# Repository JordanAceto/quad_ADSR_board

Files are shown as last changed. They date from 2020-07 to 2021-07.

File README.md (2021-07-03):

# Quad digital ADSR module

# *** Work in progress ***

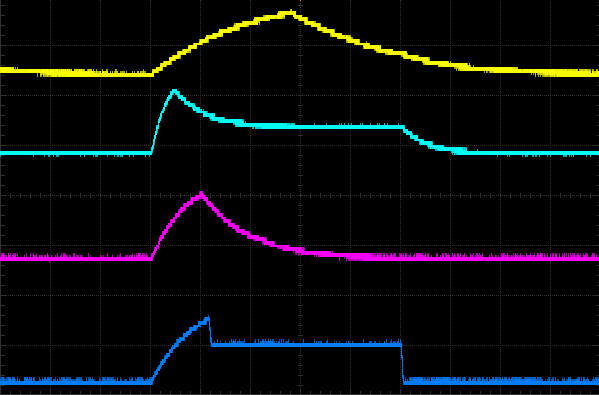
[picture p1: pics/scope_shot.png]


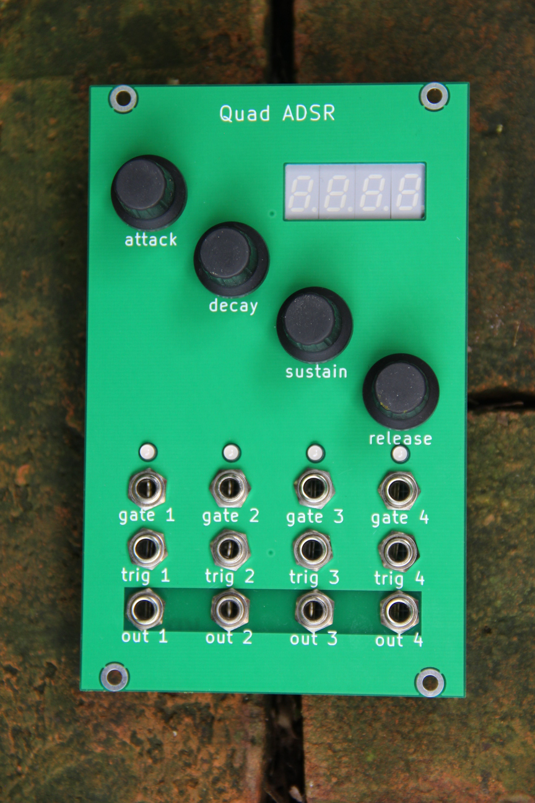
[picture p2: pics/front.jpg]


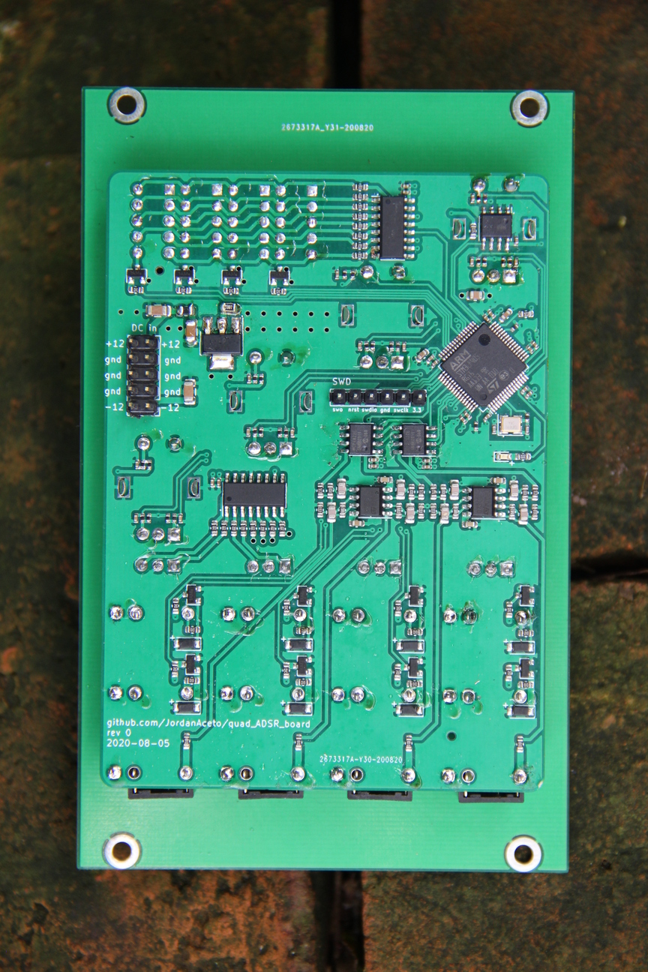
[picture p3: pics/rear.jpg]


## ADSRs are generated by an STM32 microcontroller and controlled by four encoders. A seven-segment display shows the most recently modified parameter.

One ADSR at a time is set as the "active" ADSR, which will be controlled by the encoders.

To select an ADSR as "active", the encoder push-button above a given ADSR is pressed.

The four-digit seven-segment display shows the parameter of the encoder that was most recently turned. For instance, if you just turned the decay time to 500 milliseconds, the display will show `0.500`. If you then adjust the sustain level to 68%, the display will now show `  68`. Time based parameters are shown in units of seconds, and sustain parameters are shown as 0% to 100%.

Additionally, the ADSRs can all be forced to lock to a "master" ADSR, so that that their attack, decay, sustain, and release parameters are all set the same. The four ADSRs can still be triggered independently in this mode, which makes this useful for polyphonic patches. This saves you from manually setting identical paramters four times. Lock-to-master mode is selected by performing a long push-switch press of the encoder above the desired ADSR. For instance, to force all the ADSRs to lock to the ADSR 3 settings, depress and hold the sustain encoder push-button for a few seconds. To leave lock-to-master mode, do a short click of any of the encoder push-buttons to select a new active ADSR.

A bank of four bi-color LEDs shows the active ADSR, and whether it is in independent, or lock-to-master mode.

# First rev build evaluation:
- Most of the systems work.
- __Done__ (but there is an I2C bug lurking, see the issues)~~The EEPROM has not been physically installed and EEPROM code has not been written yet.~~
- __DONE__ ~~In the code, when switching from lock-to-master mode back to independent mode: the ADSRs should go back to the settings they held before entering lock-to-master mode. Write a function called `release_ADSRs_from_master_mode` or something that accomplishes this, and call that function when leaving lock-to-master mode~~.
- __Done__ ~~The encoders should be no-detent types. I used encoders with detents and I don't like it.~~
- I tried and failed to setup encoder trigger filtering, please investigate using the timer register filters when the timers are in encoder mode. I'd like to be able to apply filtering to the encoders. They work fine and don't misfire now, but it would be nice to easily tailor how "fast" they update by addign in some filtering.
- __This really isn't that bad__ ~~The heights of the panel mount components is an issue: the 3.5mm jacks are taller than the encoders and the seven-segment display. I got everything to work by lifting the encoders and 7-seg up off the pcb before soldering, but this is lame. I think the solution is split the pcb into a main pcb and a jack pcb, and connect the two pcbs with wires. Another solution could be to create a "lifter" pcb that acts as a spacer between the main pcb and the encoders/7-seg, but this seems kind of yucky too. Think about this for a while before doing a new pcb rev.~~
- I'm having issues with getting the PLL to work for arbitrary frequencies: with some settings of M, N, and P the output frequency is not as expected. Please investigate this and figure out what I'm doing wrong.
- I used two MCP4822 DACs, but I probably could have used the 2 internal DAC channels for 2 of the ADSRs and only installed one MCP4822. Investigate if using the internal DAC for 2 channels creates any pinout conflicts, or any other kind of conflicts, for the next board revision, to try and save a DAC.
- The ADSR outputs are low: I want 10v peak ADSRs and I calculated the opamp gain resistors assuming the DACs output 3.3v peaks, but they don't. Please recalculate the gain resistors for the actual MCP4822 output with a gain of 1x. Take into account the internal DACs if you apply the suggestion above.
- __DONE__ (enabled FPU and changed signals to floats) ~~Many parts of the codebase could be optimized and improved. In particular, the ADSR code does some costly 64-bit divisions in a couple of spots. See if you can't improve this. View the `main.list` output file occasionally~~.
- __DONE__ (works ok but be on the lookout) ~~Compiler optimization is turned off right now. Turn this up to `-Os` or `-O2` and make sure that nothing breaks. There might be some volatile issues, or necessary code that gets optimized away, be careful and thorough!~~
- Otherwise the project is in pretty good shape! The prototype I built could definitely go in a rack and work with other modules.

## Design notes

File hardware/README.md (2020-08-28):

# This subdirectory contains documents for buiding the hardware for the system.

- ### All schematic capture and pcb layout is done using kicad.

- ### `main_pcb` contains everything you need to build and/or modify the main circuit board. 

- ### `front_panel` contains documents for making a low cost pcb front panel.

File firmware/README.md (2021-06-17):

# stm32f405 firmware for Quad ADSR eurorack module

## Brief description:

Four ADSR envelope generators are created in software via Direct Digital Synthesis.

Four encoders allow the user to set the attack, decay, sustain, and release parameters.

By clicking on the encoder that is in line with the jacks associated with a given ADSR, that 
ADSR is selected as the "active ADSR", and the encoders will adjust the parameters for that 
envelope only.

Performing a long button press forces all four ADSRs to lock to the ADSR associated with 
the encoder that was pressed. Now all four ADSRs will have the same attack, decay, sustain, 
and release parameters, and the encoders will update all four ADSRs simultaneously. This is
called "lock-to-master" mode. The primary use of lock-to-master mode is for polyphonic patches, 
you can easily have four ADSRs that share the same settings but can be triggered independently.

By doing a quick press of any encoder button the system will exit lock-to-master and the ADSRs will 
go back to independent mode, and their old settings will be restored.

The four digit seven-segment display shows the setting of the paramter that was most recently adjusted. 
Attack, decay, and release times are shown in seconds and milliseconds, and the sustain parameter is shown
as a percent from 0.0 to 100.

The settings for the ADSRs are remembered in EEPROM memory. The system automatically stores the settings in
the EEPROM every few minutes if they have changed.

---

## This is a CMSIS/Makefile type project.
- The bare minimum stm supplied CMSIS and startup files are included in appropriate directories.
- The rest of the code is hand written `C` which uses the CMSIS headers to manipulate registers and peripherals.
- A Makefile is included to build/clean/flash the project.
- An st-link device is used to flash the f405.

---
## Prerequisites:
- [arm-none-eabi toolchain](https://developer.arm.com/tools-and-software/open-source-software/developer-tools/gnu-toolchain/gnu-rm/downloads)
- [GNU make](https://www.gnu.org/software/make/)
- [st-link utility](https://www.st.com/en/development-tools/stsw-link004.html)
- A physical st-link device. I use an old Nucleo board.
- If you have a different preferred method of flashing STM32 chips then feel free to go wild.

---

### To build the project:
- `$ make`

### To flash an STM32f405 chip connected to an st-link programmer via the SWD header:
- `$ make write`

---

### The attack and decay curves are stored in lookup tables which are generated via a python script.

You can tweak the curves via the command line (requires python/numpy/matplotlib).

To view a plot of the attack and decay curves:
- `$ make plot_lut`

To tweak the curves and then view the results:
- `make plot_lut ATTACK_TARGET=<number between 1 and 5> NUM_TIME_CONSTANTS=<number between 3 and 10>`

To overwrite the C header and source files with tweaked curves:
- `$ make write_lut ATTACK_TARGET=<number between 1 and 5> NUM_TIME_CONSTANTS=<number between 3 and 10>`

To overwrite the C header and source files with default curves:
- `$ make write_lut`

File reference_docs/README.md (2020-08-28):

# The `reference_docs` directory contains various technical documents related to the parts used by the system

- ### `stm32_docs` contains the data sheet, reference manual, and errata for the stm32f405 microcontroller used by the system, as well as the cortex-M4 programmers manual.

- ### `misc_datasheets` contains datasheets for the other electronic parts used by the system: the DAC, opamps, shift registers, LEDs, etc.

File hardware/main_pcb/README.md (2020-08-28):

# Main pcb

## This subdirectory contains the documents needed to build and/or modify the main pcb.

---
### The general outline of the hardware:
- An stm32f405 generates four ADSRs digitally using DDS/look up tables.
- Four encoders control the Attack, Decay, Sustain, and Release parameters.
- The ADSR signals are sent to two MCP4822 SPI DACs.
- The MCP4822 DACs feed four opamp lowpass filters which smooth, scale, and buffer the output signals.
- A seven segment LED display and four bicolor LEDs are driven by shift registers connected to the SPI bus.
- An EEPROM is driven by the I2C bus.
- NPN transistors buffer the microcontroller inputs from the outside world.
- A standard Eurorack style power input header is used for the +/- 12vdc power input.
- The opamps are powered directly by the +/- 12vdc input.
- A 3.3v regulator provides power to the low voltage parts of the system.

---
### `kicad_docs` contains all the files needed to open the project in kicad.
- If you want to modify the project, go in here.
---
### `construction_docs` contains the files needed to build the project:
- A pdf copy of the schematic.
- An interactive BOM that can be opened in a web browser.
- Complete gerbers for the pcb, and a zipped copy of all the gerbers.
- Files for using the cheap smt assembly service from jlcpcb. Most of the small parts are included. The DACs and EEPROM were left out because they were extended parts at jlc at the time I ordered.
- If you use the jlcpcb assembly service, you'll still need to hand install the DACs, EEPROM, and all the through hole parts.

---
### `pics` contains a few rendered pics of the pcb

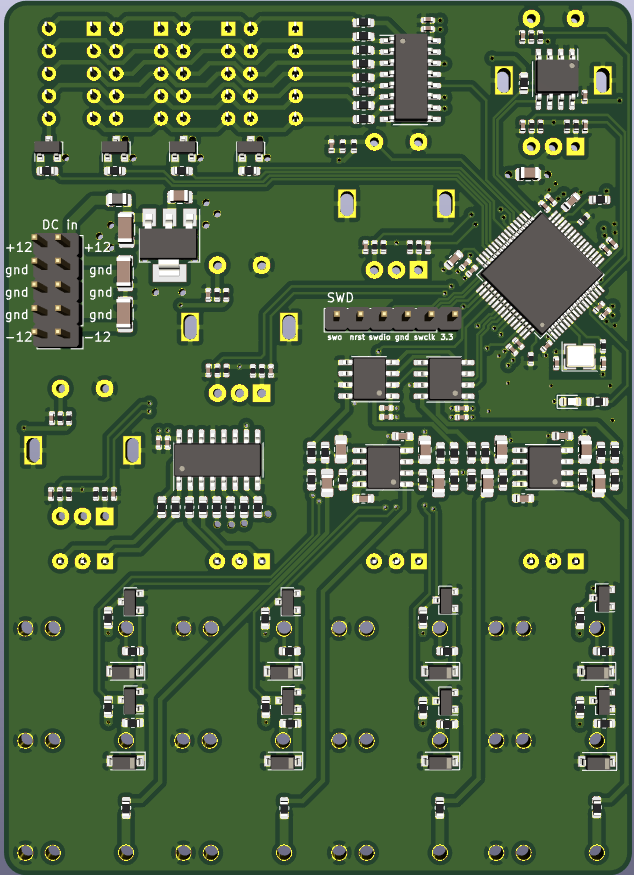
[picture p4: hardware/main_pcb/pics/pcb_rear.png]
pcb rear


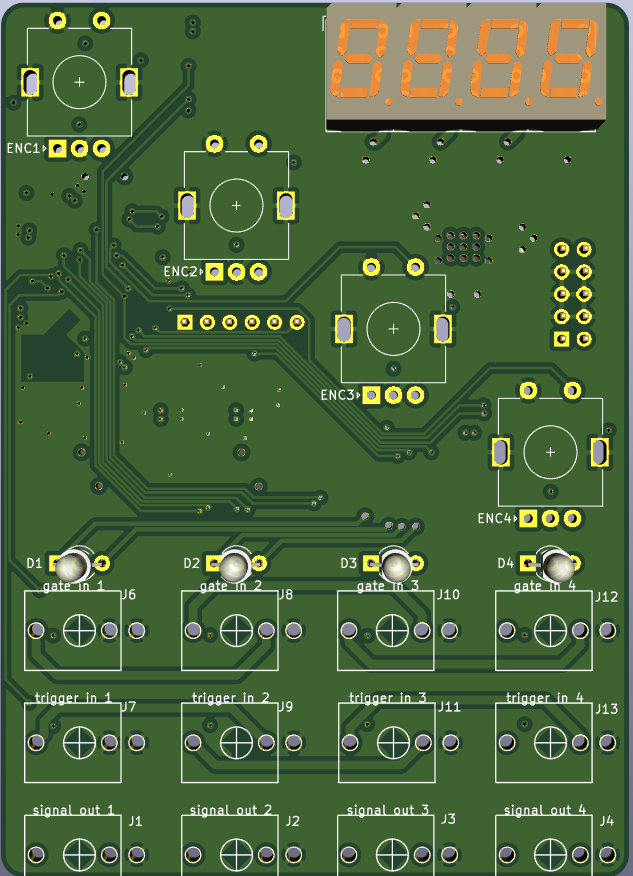
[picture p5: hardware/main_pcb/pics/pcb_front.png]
pcb front


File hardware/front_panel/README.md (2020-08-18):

# Quad ADSR front panel

Low cost pcb front panel option

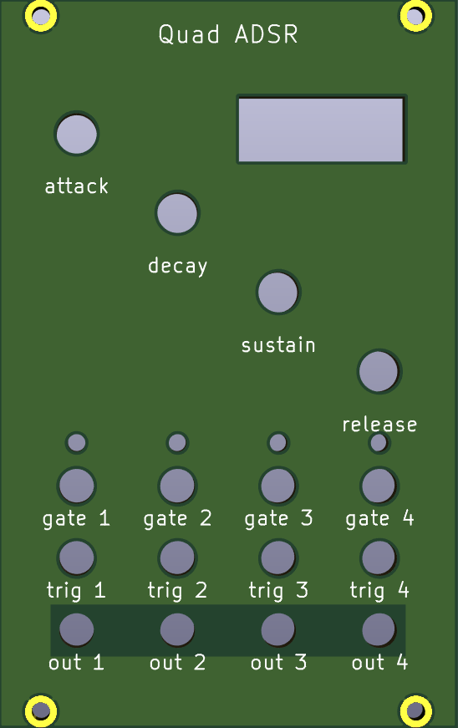
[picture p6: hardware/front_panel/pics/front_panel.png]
front panel


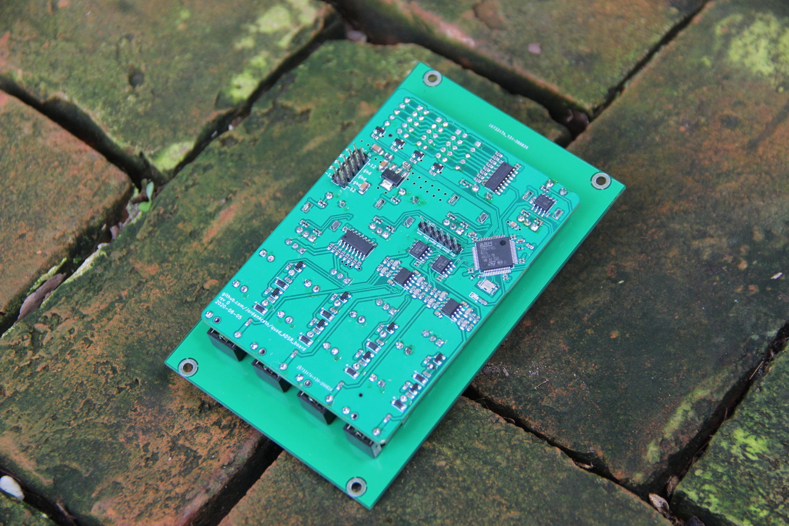
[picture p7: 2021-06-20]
pics/rear_angle.jpg

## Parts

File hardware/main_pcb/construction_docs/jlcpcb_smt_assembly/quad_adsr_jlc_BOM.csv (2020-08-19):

Designator | Quantity | Value | Footprint | LCSC Part #
C1, C2, C4, C5, C7, C8, C10, C11, | 8 | 10nF | 0402 | C15195
C3, C6, C9, C12, C16, C17, C18, C19, C20, C21, C22, C23, C24, C25, C26, C27, C28, C29, C30, C31, C32, C49, C50, C53, | 24 | 100nF | 0402 | C1525
C13, C51, C52, | 3 | 10uF | 1206 | C13585
C14, C15, | 2 | 10uF | 0805 | C15850
C33, C34, C35, C36, | 4 | 100nF | 0603 | C14663
C37, C38, C39, C40, C41, C42, C43, C44, | 8 | 2n2 | 0805 | C28260
C45, C46, | 2 | 2.2uF | 0603 | C23630
C47, C48, | 2 | 12pF | 0402 | C1547
D5, | 1 | LED | 0603 | C72043
D6, D7, D8, D9, D10, D11, D12, D13, | 8 | 1N4148W | SOD-123 | C81598
FB1, | 1 | Ferrite_Bead_Small | 0805 | C1015
HSE1, | 1 | 16MHz | SMD-3225_4P | C13738
Q1, Q2, Q3, Q4, Q5, Q6, Q7, Q8, Q9, Q10, Q11, Q12, | 12 | MMBT3904 | SOT-23 | C20526
R1, R2, R3, R4, R7, R8, R9, R10, R13, R14, R15, R16, R19, R20, R21, R22, R82, R83, | 18 | 10k | 0402 | C25744
R5, R11, R17, R23, | 4 | 4k7 | 0402 | C25900
R6, R12, R18, R24, R84, | 5 | 100 | 0402 | C25076
R25, R34, R35, R36, R50, R52, R54, R56, R58, R60, R62, R64, | 12 | 10k | 0603 | C25804
R26, R27, R28, R29, R30, R31, R32, R33, R37, R38, R39, R40, R41, R42, R43, R44, | 16 | 390 | 0603 | C23151
R45, R46, R47, R48, | 4 | 1k | 0603 | C21190
R49, R51, R53, R55, R57, R59, R61, R63, | 8 | 100k | 0603 | C25803
R65, R66, R73, R74, | 4 | 50k | 0603 | C23196
R67, R68, R75, R76, | 4 | 200k | 0603 | C25811
R69, R70, R77, R78, | 4 | 33k | 0603 | C4216
R71, R72, R79, R80, | 4 | 68k | 6030 | C23231
R81, | 1 | 2k2 | 0603 | C4190
R85, R86, | 2 | 4k7 | 0603 | C23162
U2, U6, | 2 | 74HC595 | SOIC-16_3.9x9.9_1.27P | C5947
U7, | 1 | AMS1117-3.3 | SOT-223 | C6186
U8, U11, | 2 | TL072 | SOIC-8_3.9x4.9_1.27P | C6961
U12, | 1 | STM32F405RGTx | LQFP-64_10x10_P0.5P | C15742

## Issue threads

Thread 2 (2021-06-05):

Trouble hitting arbitrary frequencies with PLL

JordanAceto, 2021-06-05:
In the RCC clock configuration code, I am not able to set the PLL multipliers/dividers such that the output frequency is as expected for all frequencies.

Right now I have it hitting 50MHz with M, N, and P settings that make sense.

But, if I try to set the clock to 84MHz using M, N, and P settings that seem like they should work, the actual output frequency is not correct.

See the code in RCC.c for details. There is commented out code to output the divided PLL on one of the GPIO pins for monitoring. You can also toggle the LED or something in one of the timer ISRs to see if the frequencies make sense.

I suspect this may have something to do with the order of the clock initialization, or perhaps I'm not setting up the FLASH wait states correctly for fast clocks.

50MHz is probably fine for the final clock frequency, but I'd like to know what I'm doing wrong and be able to set the clock to arbitrary (legal) frequencies.

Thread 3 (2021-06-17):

I2C2 goes into infinite loop without small delay

JordanAceto, 2021-06-17:
After writing to the EEPROM via I2C2, if you attempt to read or write again immediately the system will go into an infinite loop.

A hack that seems to stop this is putting a few millisecond delay at the end of the I2C2_memory_write function.

However, this is not ideal, as the delay could happen at an annoying time if the user is playing, causing a discontinuity.

Something about the way I'm writing/reading/initializing I2C2 is wrong, but I'm not sure what it is yet. Please investigate and fix the I2C2 code, and then remove the delay at the end of the I2C2_memory_write function.

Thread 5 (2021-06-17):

ADSR outputs are low

JordanAceto, 2021-06-17:
The outputs of the ADSRs are supposed to range [0v, +10v], but they don't.

I calculated the gain of the opamp lowpass filters/level shifters assuming the DACs went up to +3.3v, but they don't, more like +2v and change.

The exact amplitude of the ADSRs isn't critical, but it would be nice if they went to a level that seemed on purpose :P

Please recalculate the gain-setting resistors of the opamps so that the ADSR final outputs go to +10 volts.

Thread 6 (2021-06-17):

TIM6 and TIM7 init could be cleaned up

JordanAceto, 2021-06-17:
The initialization code for timers TIM6 and TIM7 uses magic numbers, and I'm not even sure what frequency I was trying to hit with  TIM7.

It should be possible to use the value of the system clock frequency to calculate the PSC and ARR register values to hit a desired  timer frequency.

TIM6 must match the sample rate for the ADSRs. It's important that this one is fast and not-too-jittery.

TIM7 is not critical, it updates the UI and can be pretty slow as long as the LEDs don't flicker. I think I was going for 1kHz.

Please remove the magic numbers and use the symbol for the system clock frequency to calculate the desired register values, and include some comments about what the times mean.

JordanAceto, 2021-07-04:
Done

Closed 2021-07-04.

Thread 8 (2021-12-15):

DAC2 CS pin is on a bad pin

JordanAceto, 2021-12-15:
The chip select pin for DAC2 is PB4 on the stm32. This is also the NJTRST JTAG pin. There is a workaround in the GPIO.c file that deals with the MODER bits, but it would be better if it were on a different pin, there are plenty available. See the comment in GPIO.c set_SPI_CS_pins_to_output() function implementation for more details.

When a board revision happens, consider moving this pin. Changes will need to be made to the PCB layout, GPIO.c, and GPIO.h

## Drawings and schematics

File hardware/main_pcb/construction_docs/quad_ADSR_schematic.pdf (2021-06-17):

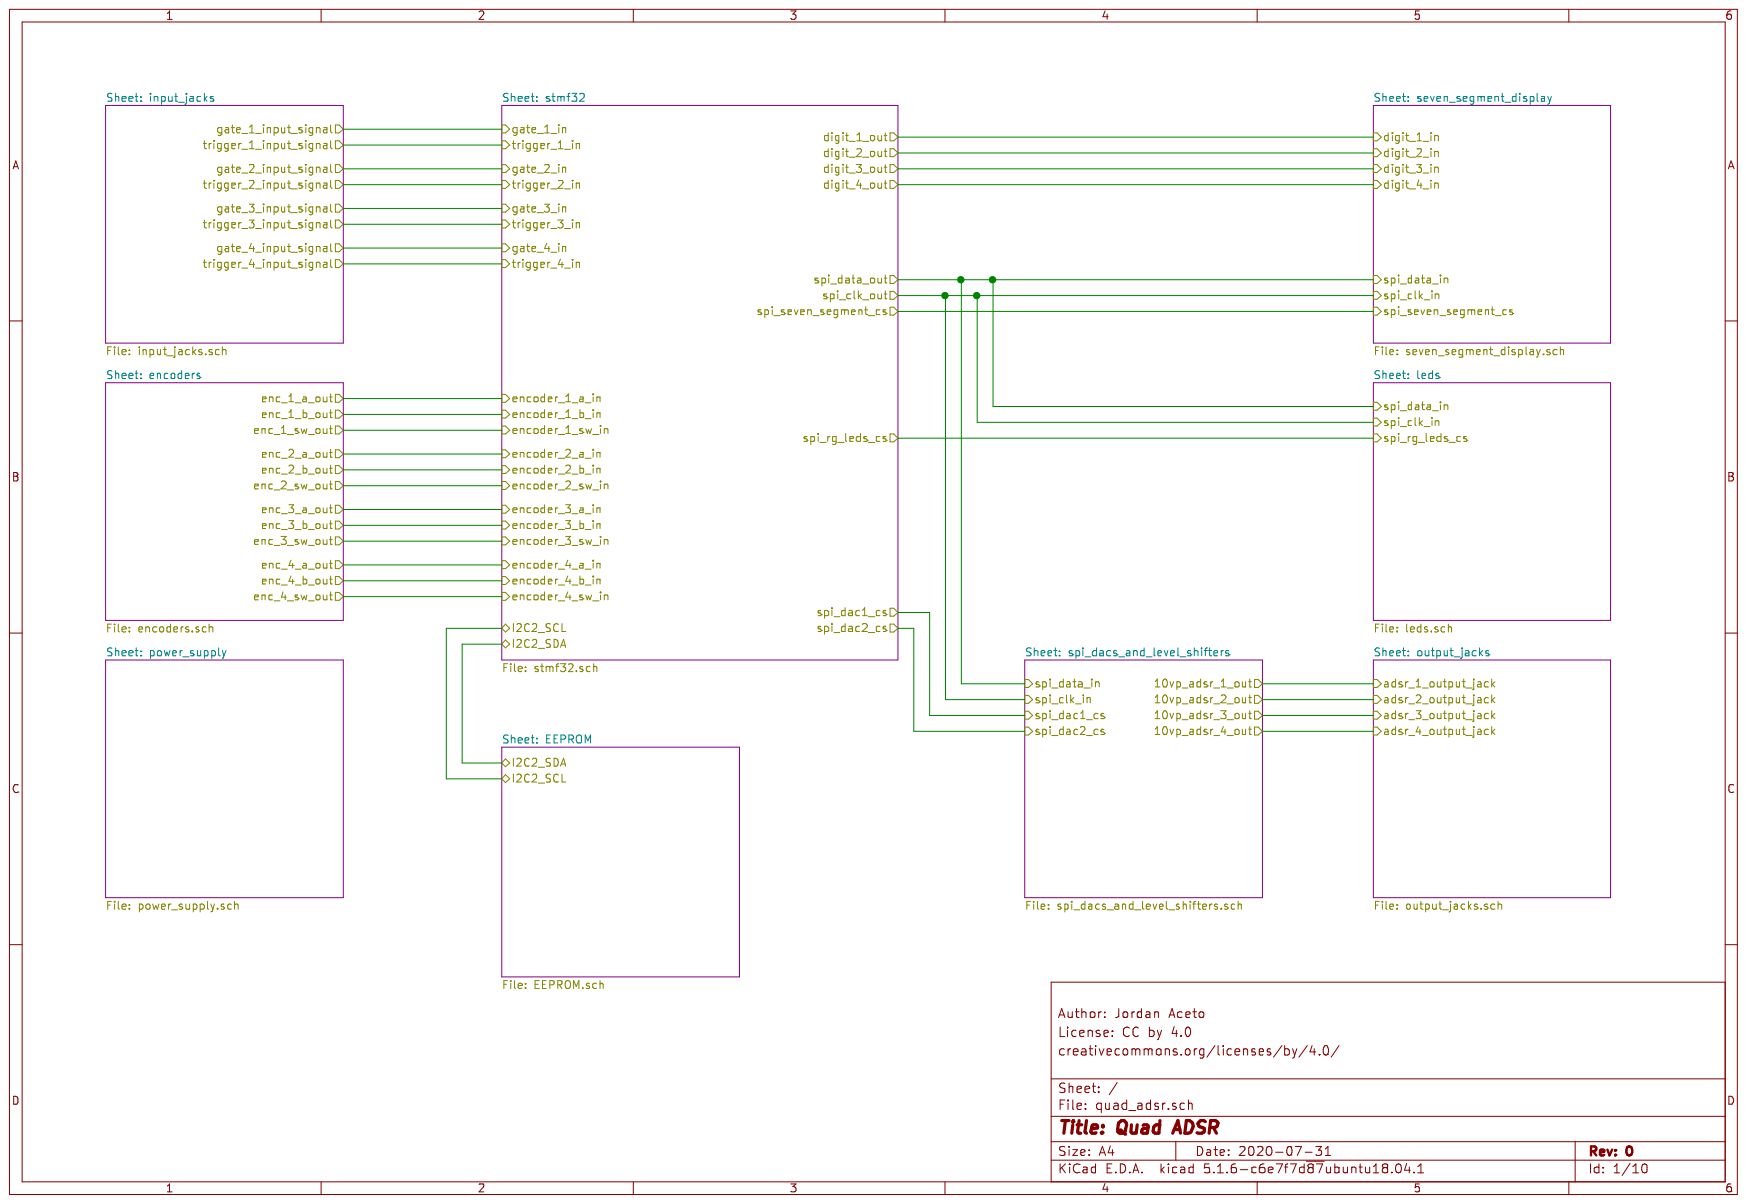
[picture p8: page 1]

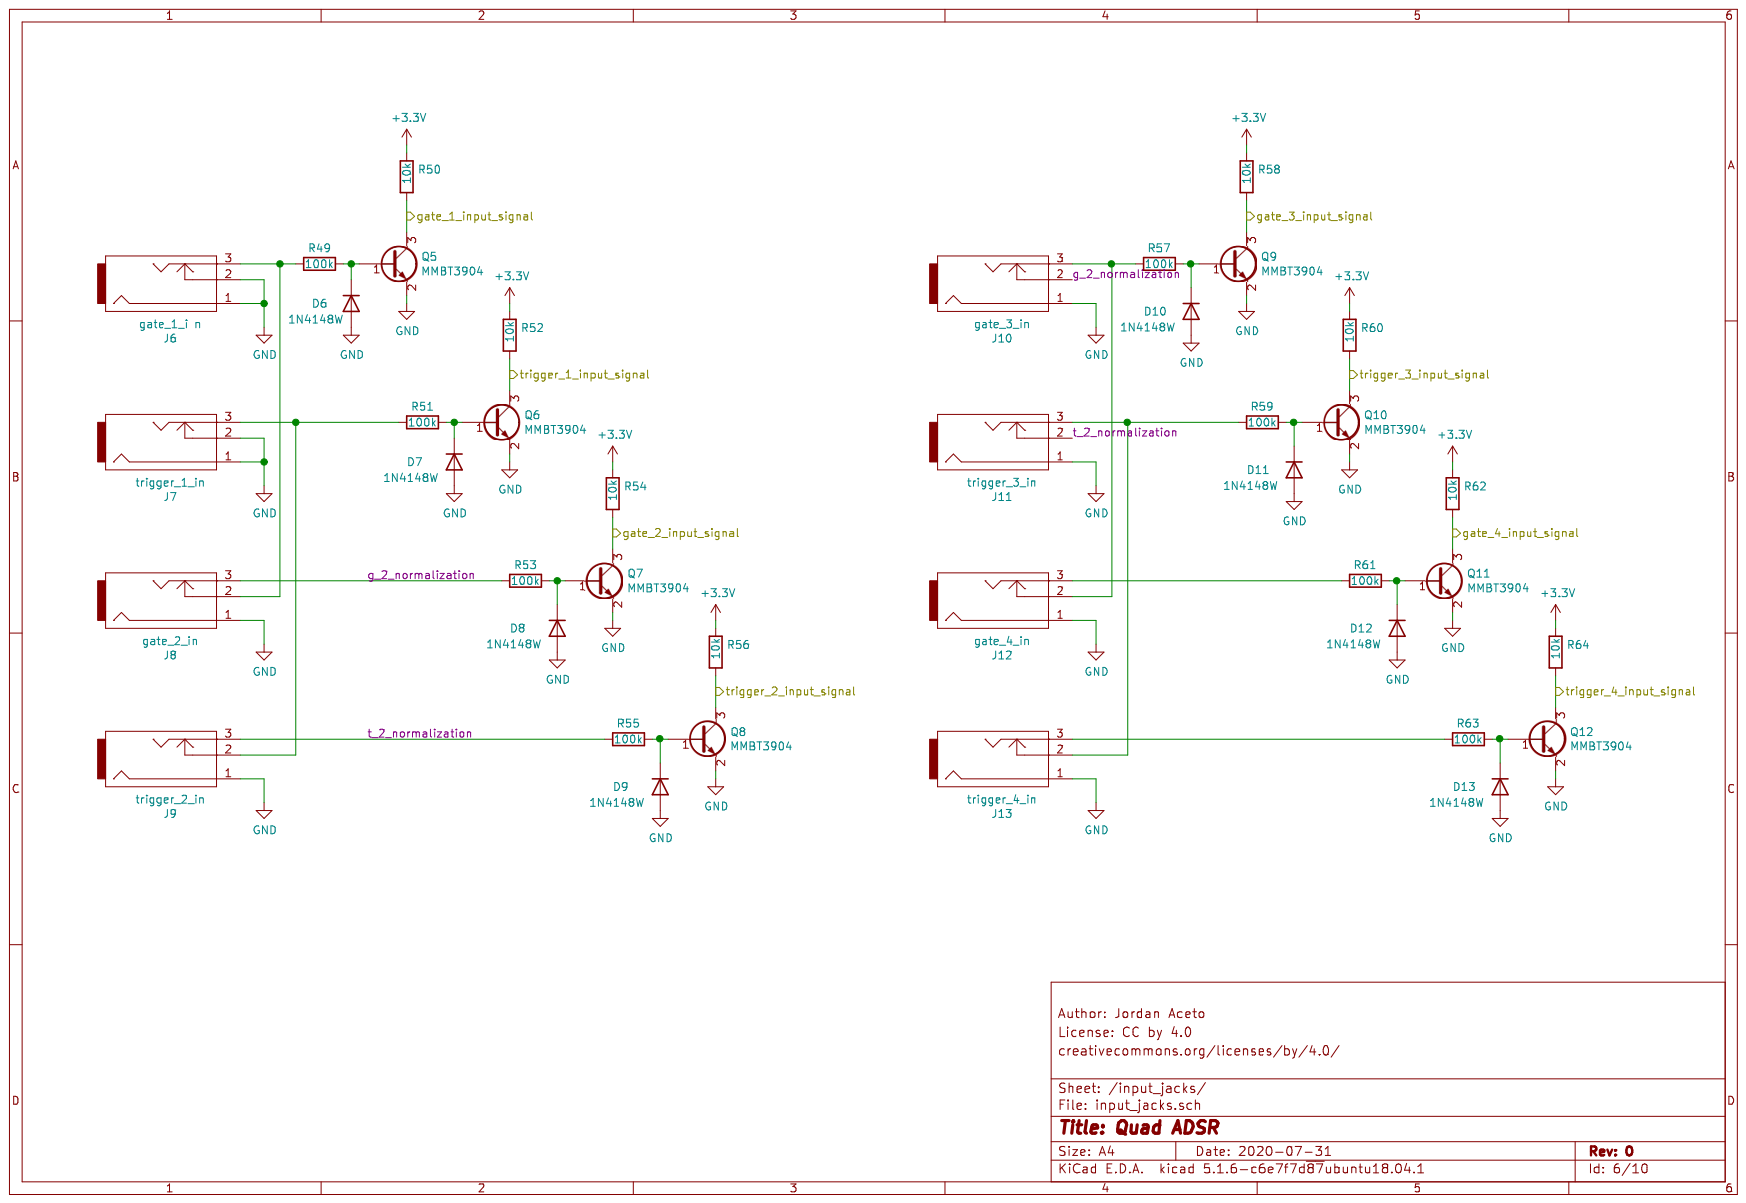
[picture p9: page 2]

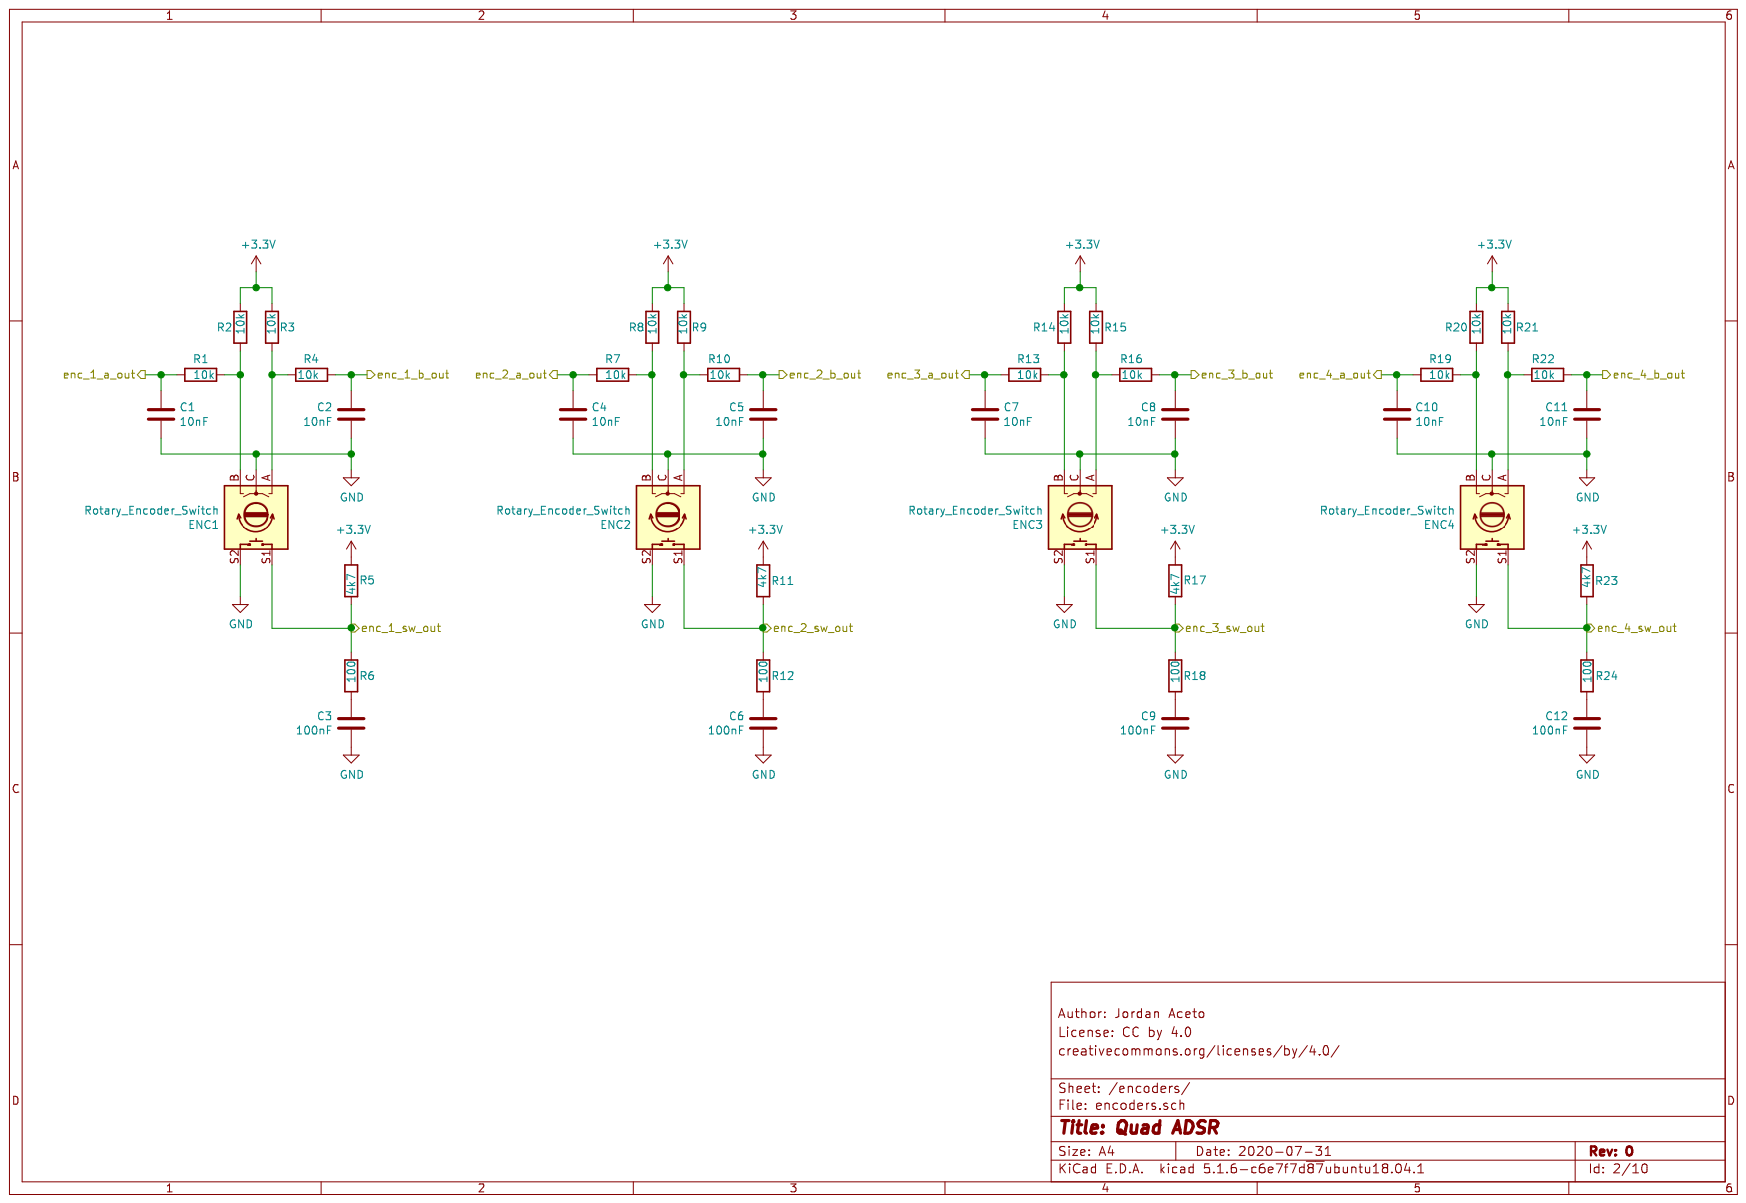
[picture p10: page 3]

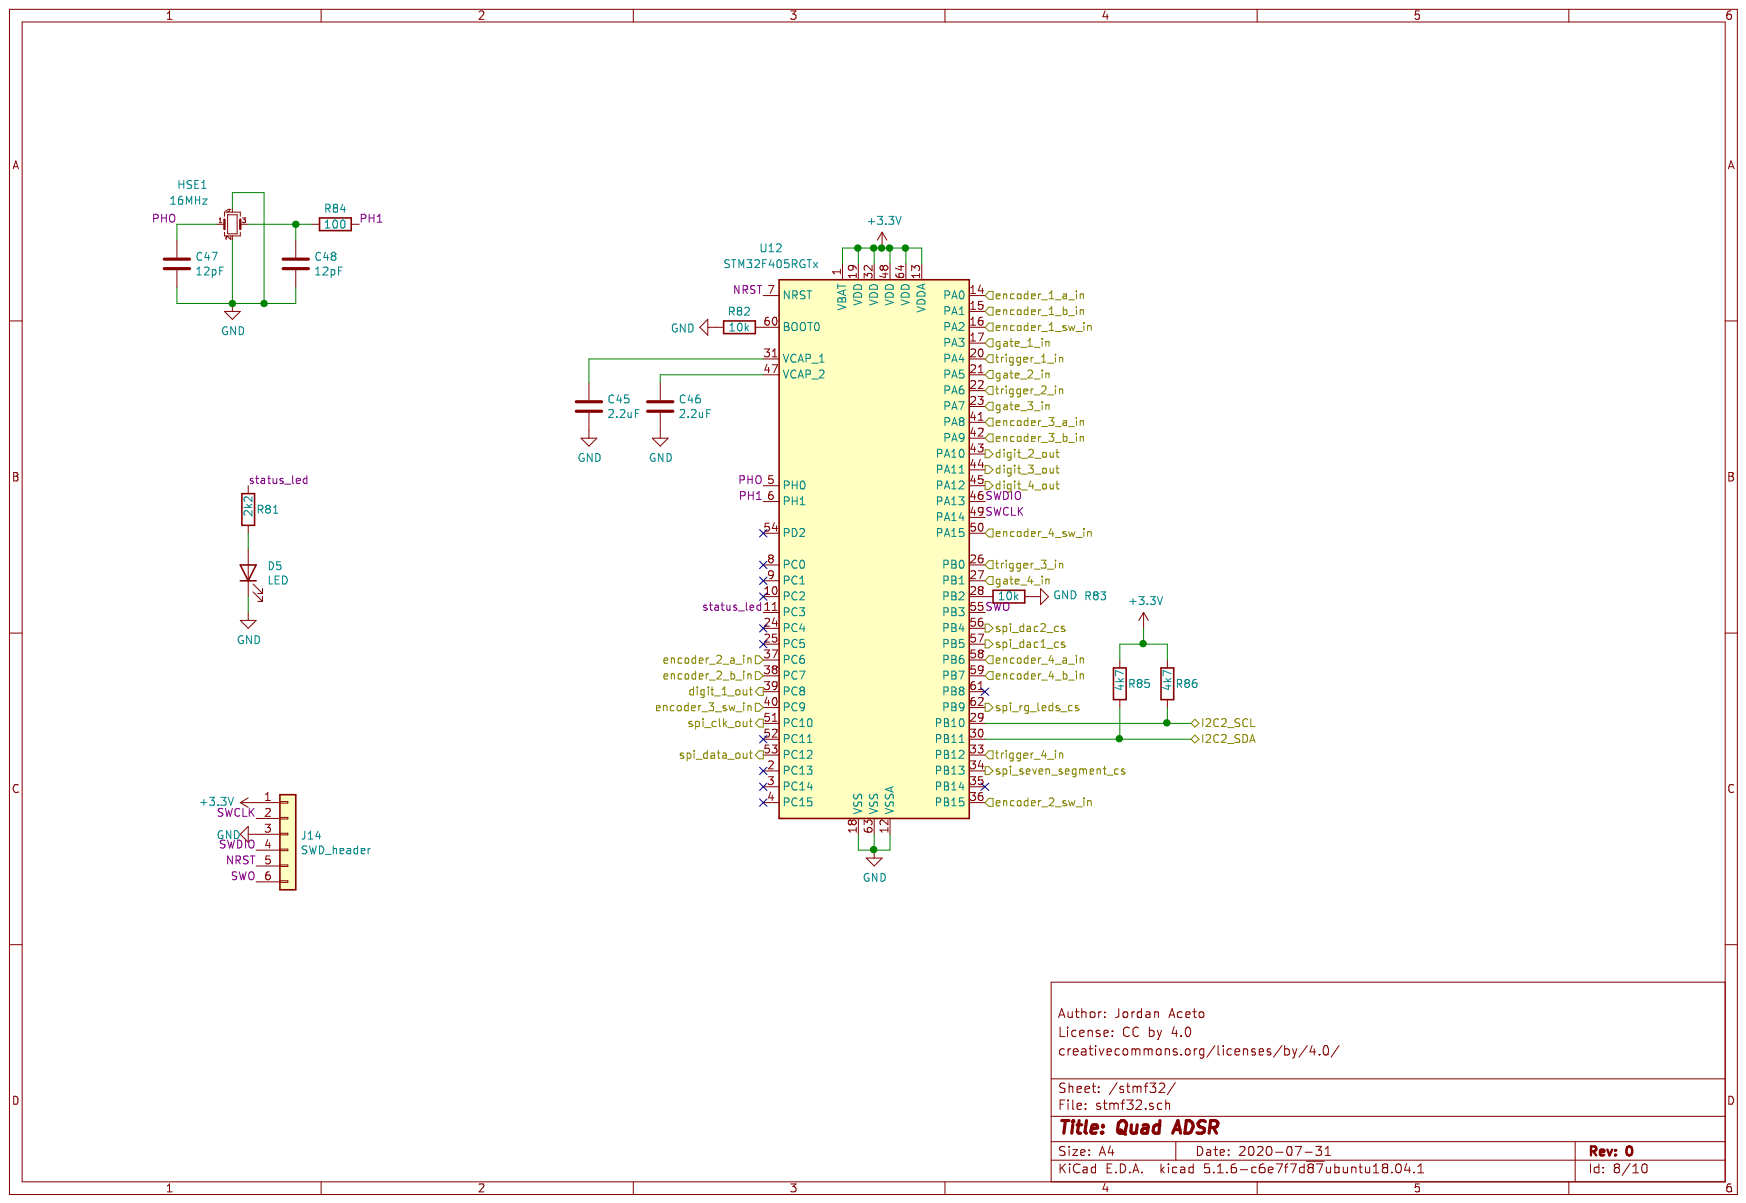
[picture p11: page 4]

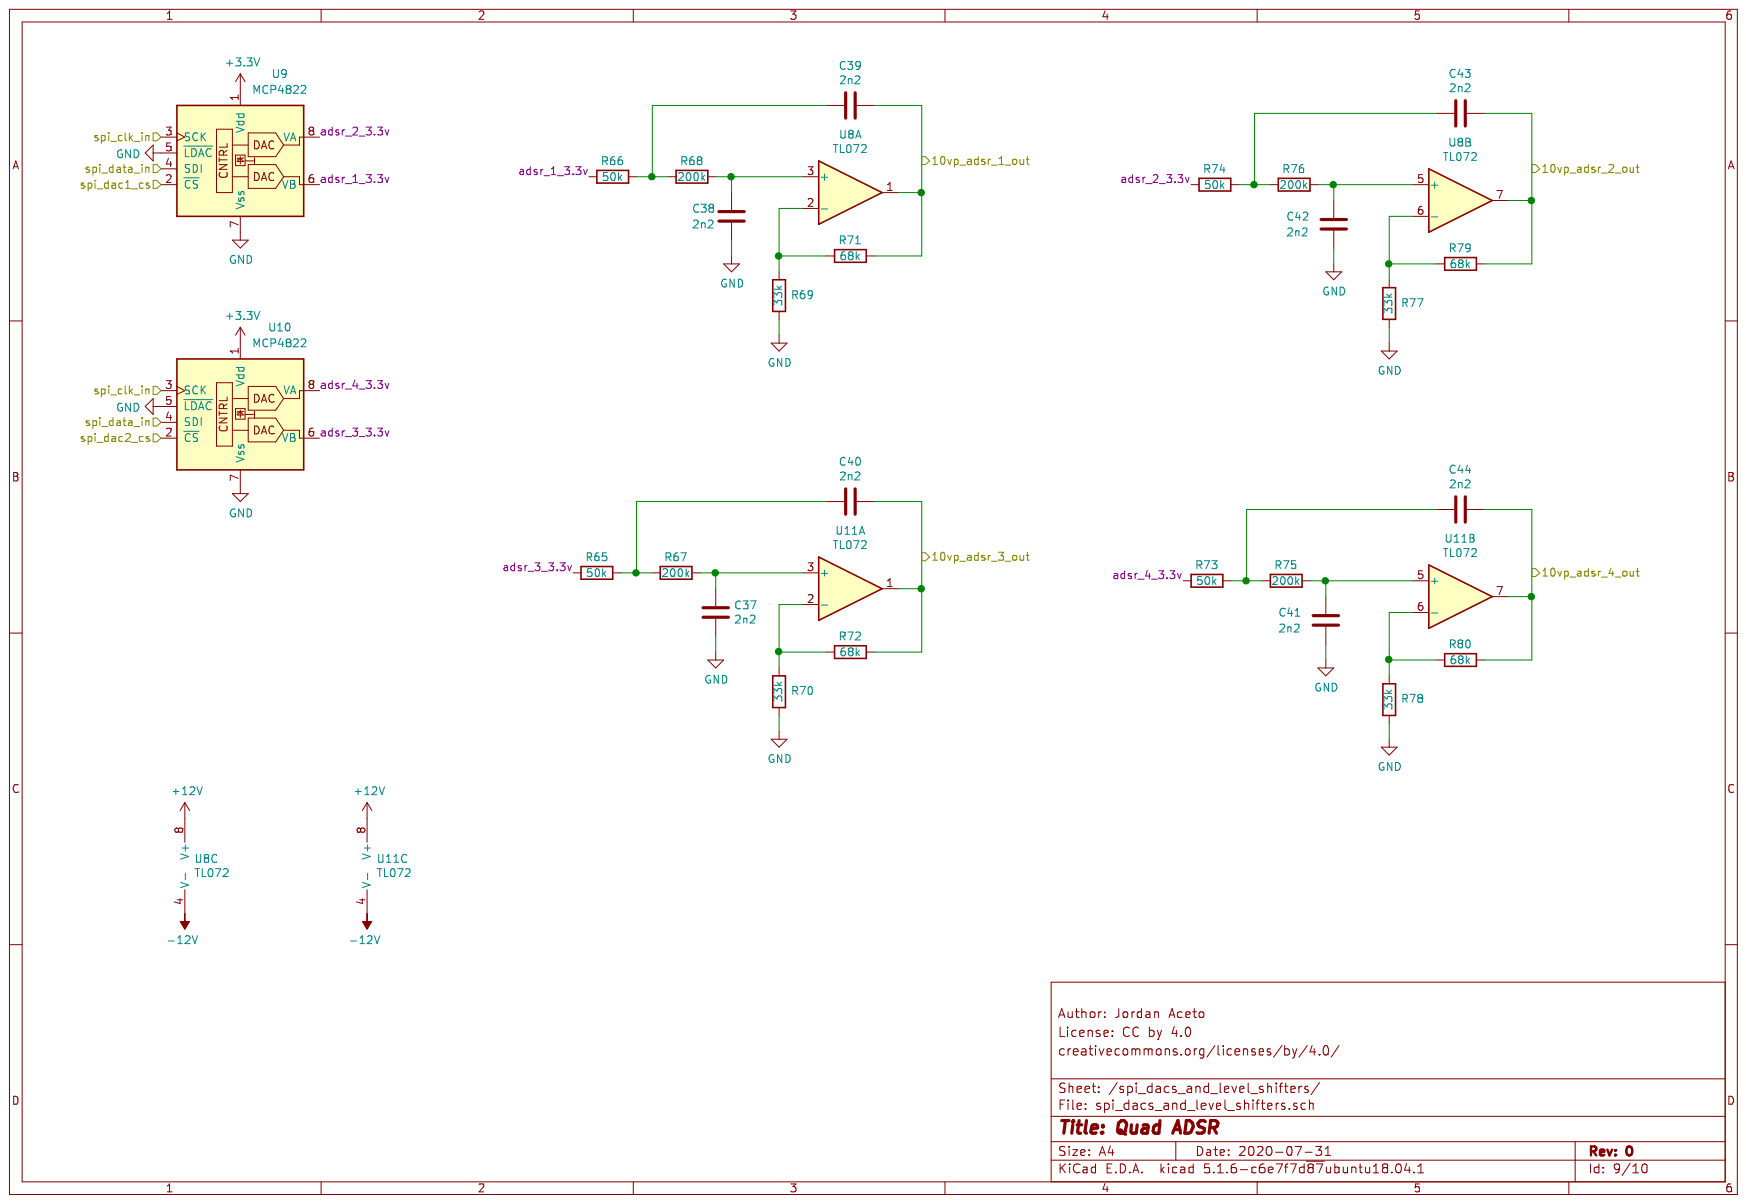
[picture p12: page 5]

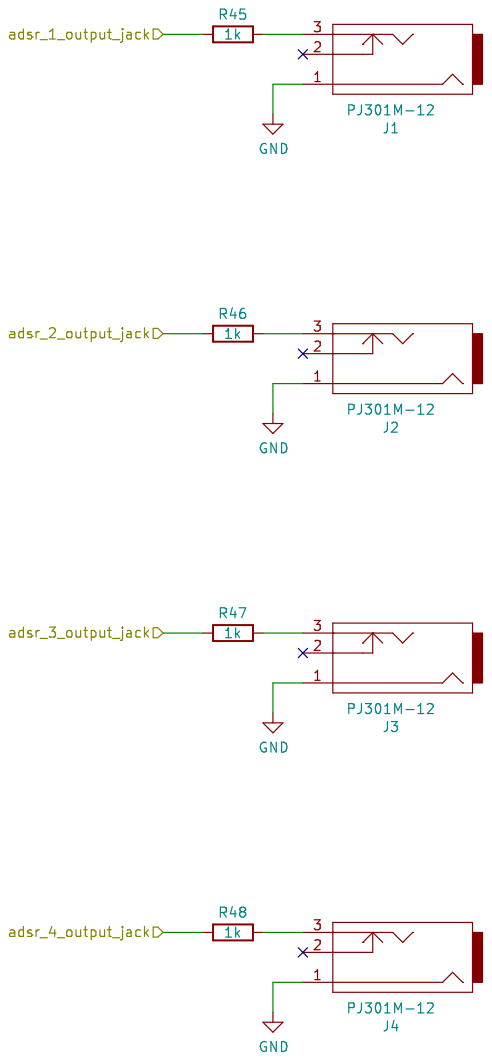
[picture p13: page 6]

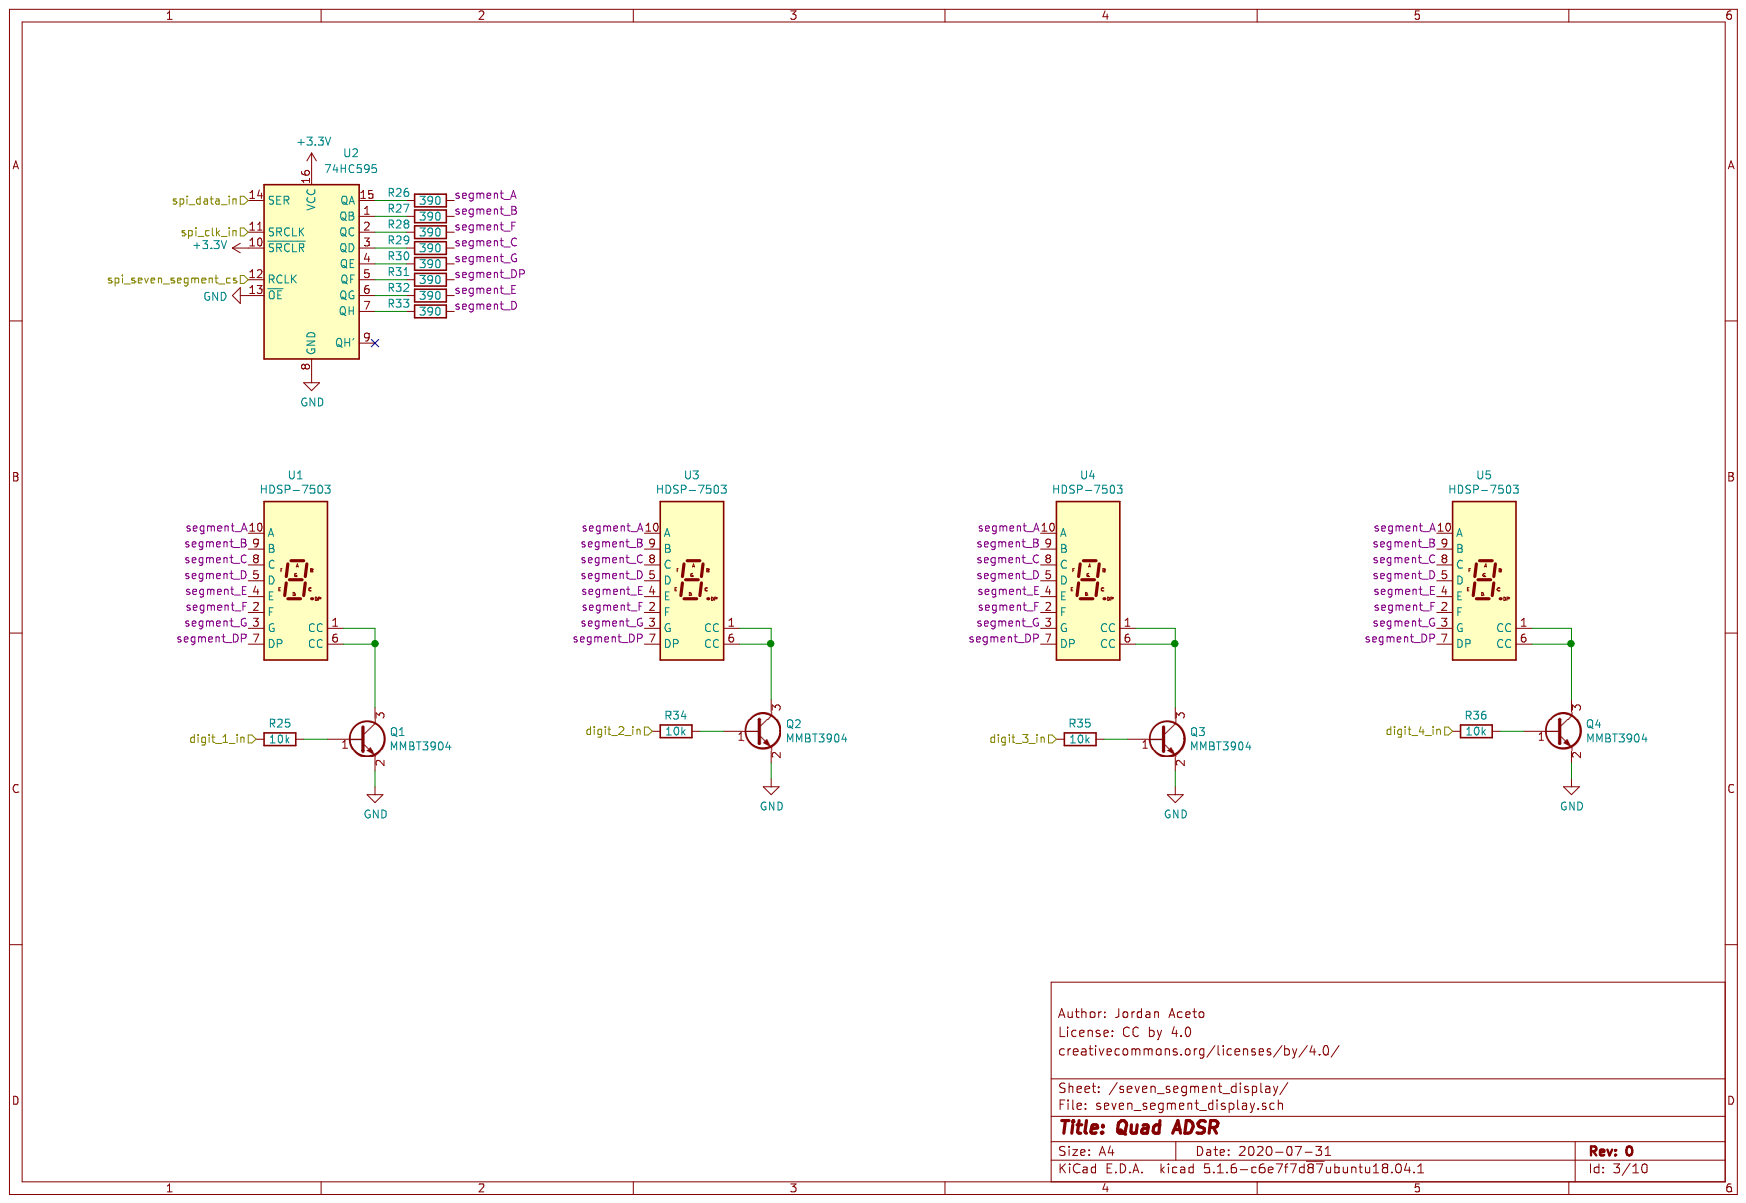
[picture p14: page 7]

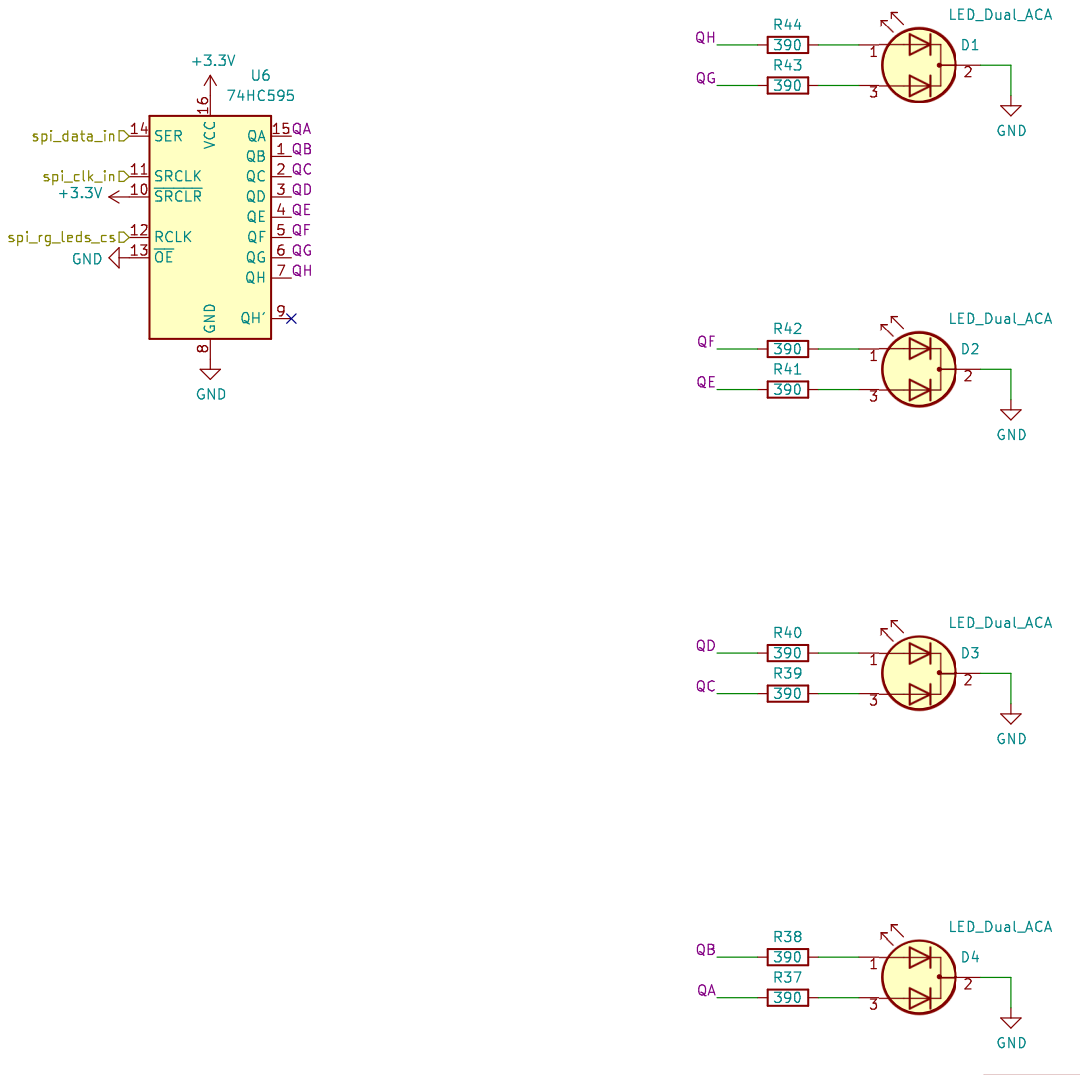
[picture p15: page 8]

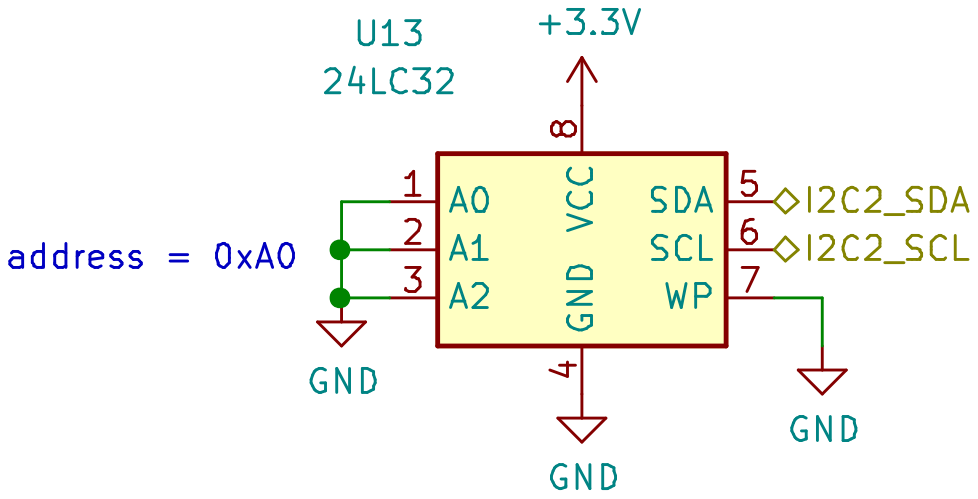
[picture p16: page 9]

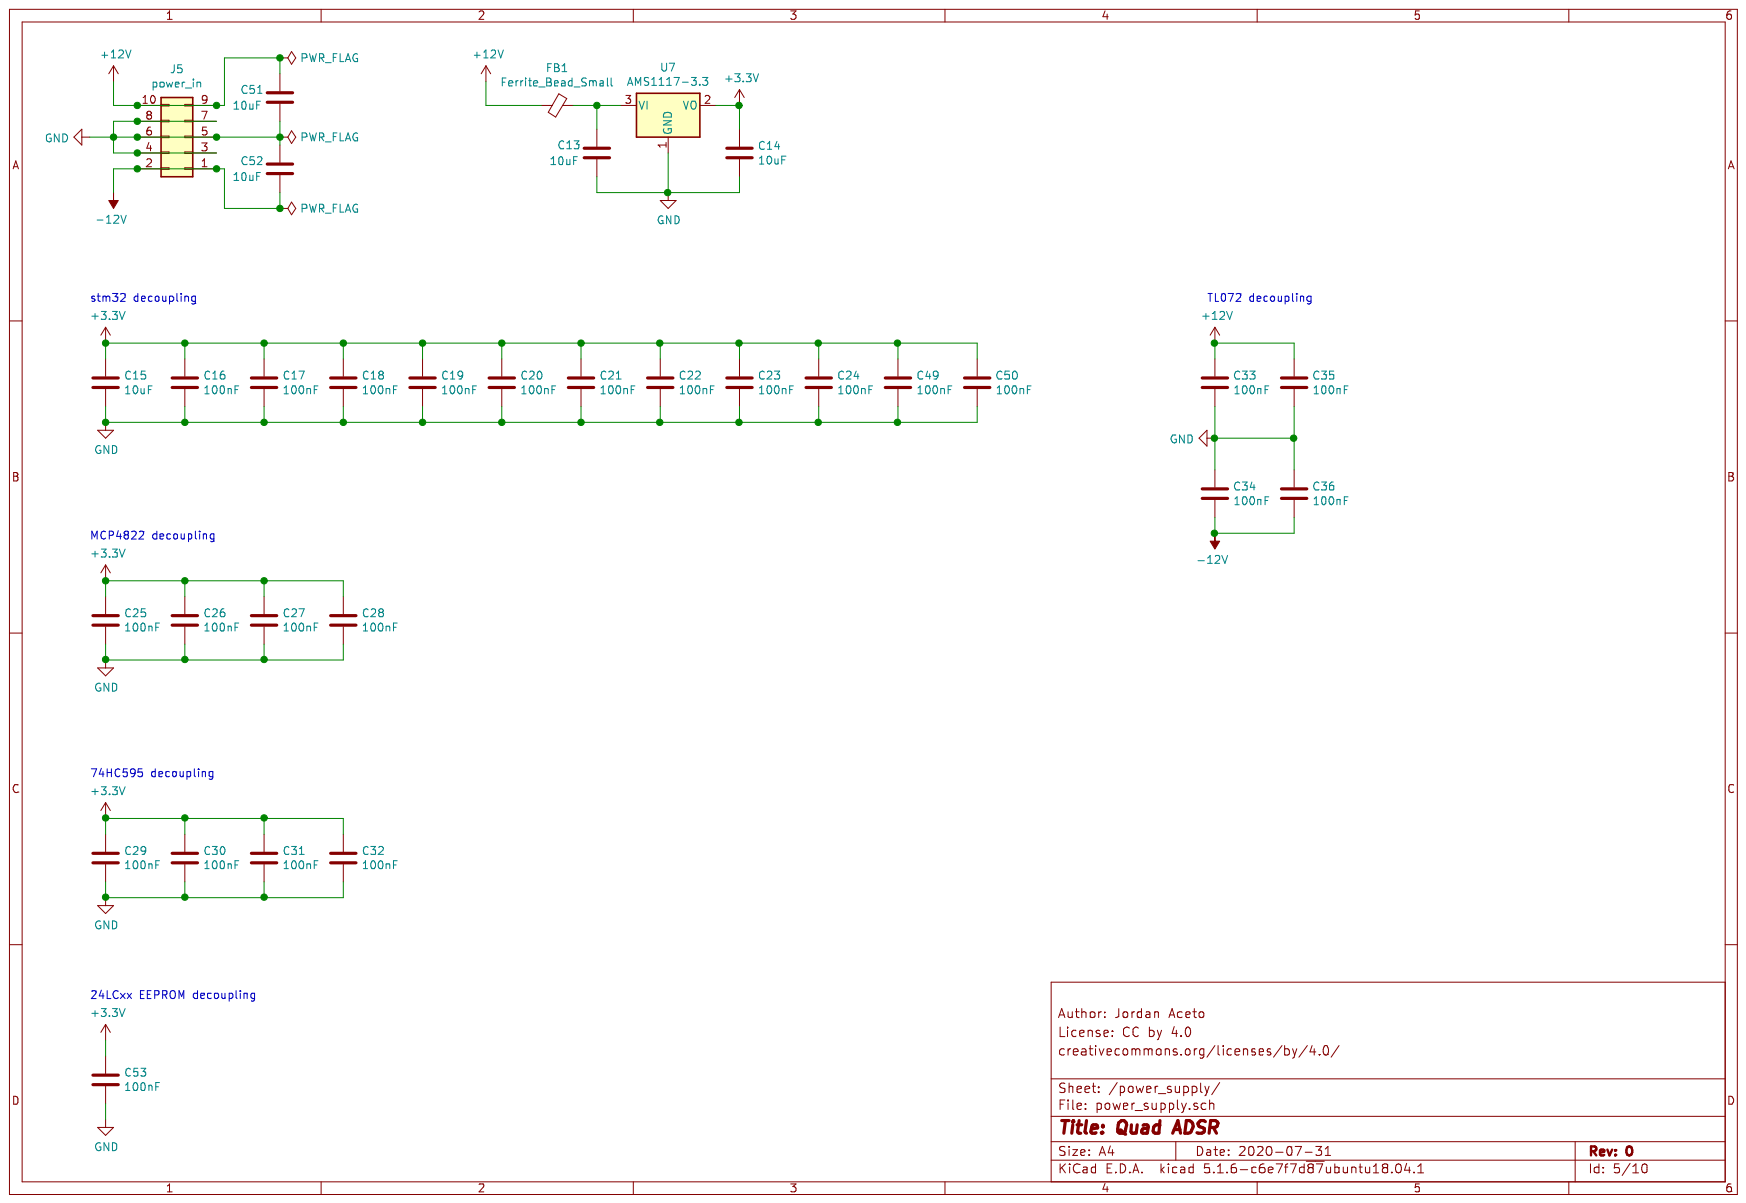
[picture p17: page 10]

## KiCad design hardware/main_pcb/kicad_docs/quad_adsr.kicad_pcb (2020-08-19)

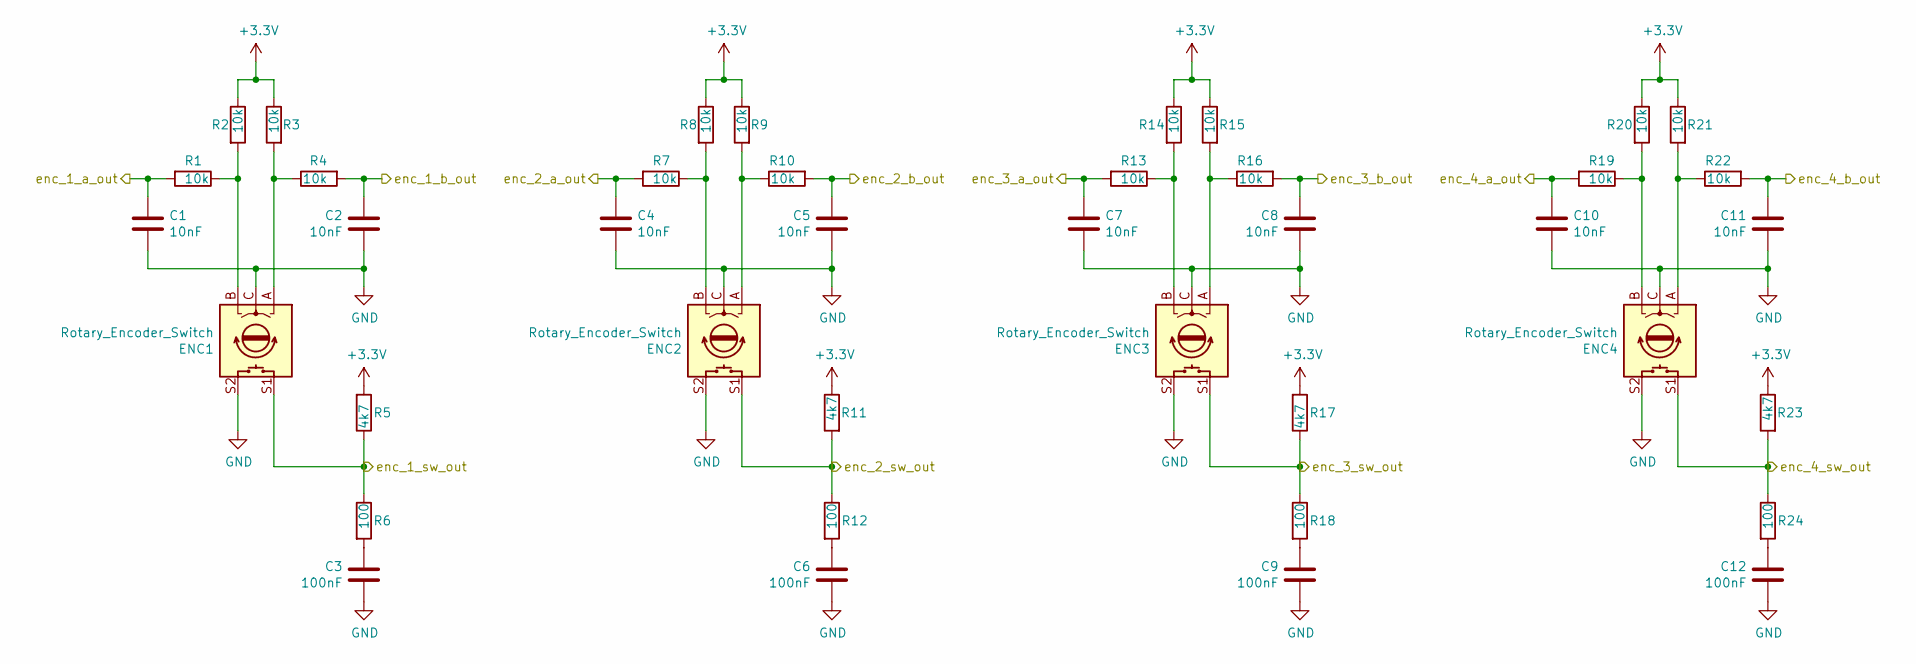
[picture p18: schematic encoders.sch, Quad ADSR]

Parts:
C1, C2, C4, C5, C7, C8, C10, C11: 10nF; C_0402_1005Metric
C3, C6, C9, C12: 100nF; C_0402_1005Metric
ENC1, ENC2, ENC3, ENC4: Rotary_Encoder_Switch; RotaryEncoder_Alps_EC11E-Switch_Vertical_H20mm
R1, R2, R3, R4, R7, R8, R9, R10, R13, R14, R15, R16, R19, R20, R21, R22: 10k; R_0402_1005Metric
R5, R11, R17, R23: 4k7; R_0402_1005Metric
R6, R12, R18, R24: 100; R_0402_1005Metric

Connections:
+3V3: R2.1, R3.1, R5.2, R8.1, R9.1, R11.1, R14.1, R15.1, R17.2, R20.1, R21.1, R23.1; also elsewhere on the board
/encoders/enc_1_a_out: C1.1, R1.2; also elsewhere on the board
/encoders/enc_1_b_out: C2.1, R4.2; also elsewhere on the board
/encoders/enc_1_sw_out: ENC1.S1, R5.1, R6.1; also elsewhere on the board
/encoders/enc_2_a_out: C4.1, R7.2; also elsewhere on the board
/encoders/enc_2_b_out: C5.1, R10.2; also elsewhere on the board
/encoders/enc_2_sw_out: ENC2.S1, R11.2, R12.1; also elsewhere on the board
/encoders/enc_3_a_out: C7.1, R13.2; also elsewhere on the board
/encoders/enc_3_b_out: C8.1, R16.2; also elsewhere on the board
/encoders/enc_3_sw_out: ENC3.S1, R17.1, R18.1; also elsewhere on the board
/encoders/enc_4_a_out: C10.1, R19.2; also elsewhere on the board
/encoders/enc_4_b_out: C11.1, R22.2; also elsewhere on the board
/encoders/enc_4_sw_out: ENC4.S1, R23.2, R24.1; also elsewhere on the board
GND: C1.2, C2.2, C3.2, C4.2, C5.2, C6.2, C7.2, C8.2, C9.2, C10.2, C11.2, C12.2, ENC1.C, ENC1.MP, ENC1.S2, ENC2.C, ENC2.MP, ENC2.S2, ENC3.C, ENC3.MP, ENC3.S2, ENC4.C, ENC4.MP, ENC4.S2; also elsewhere on the board
unnamed: C3.1, R6.2
unnamed: C6.1, R12.2
unnamed: C9.1, R18.2
unnamed: C12.1, R24.2
unnamed: ENC1.A, R3.2, R4.1
unnamed: ENC1.B, R1.1, R2.2
unnamed: ENC2.A, R9.2, R10.1
unnamed: ENC2.B, R7.1, R8.2
unnamed: ENC3.A, R15.2, R16.1
unnamed: ENC3.B, R13.1, R14.2
unnamed: ENC4.A, R21.2, R22.1
unnamed: ENC4.B, R19.1, R20.2

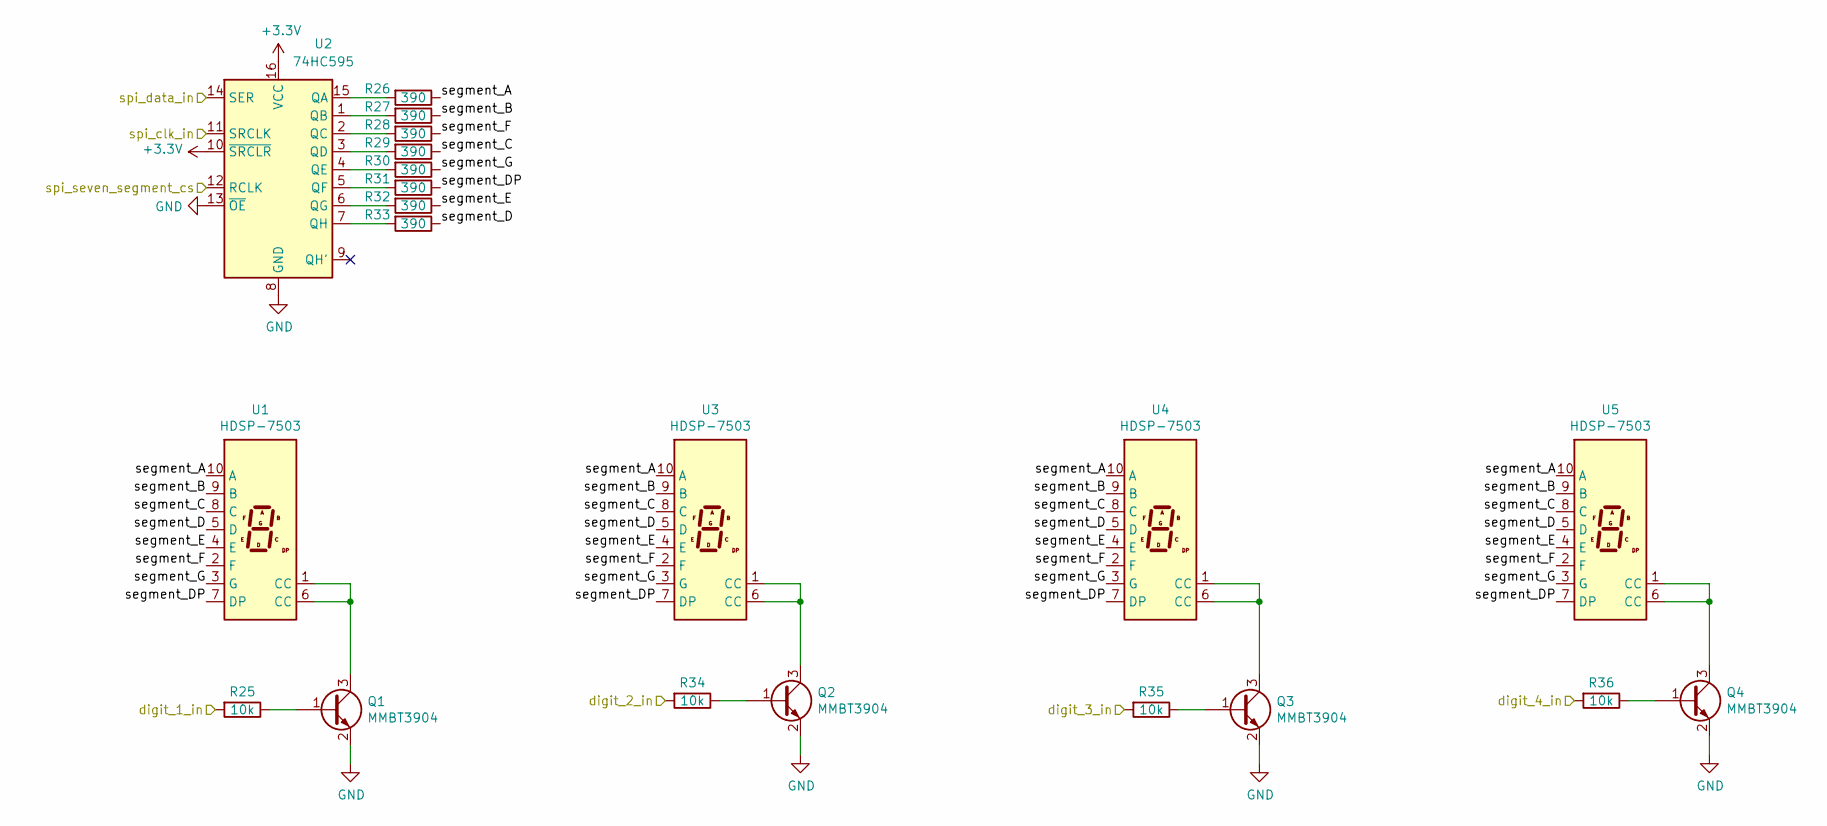
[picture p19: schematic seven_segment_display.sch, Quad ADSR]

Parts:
Q1, Q2, Q3, Q4: MMBT3904; SOT-23
R25, R34, R35, R36: 10k; R_0603_1608Metric
R26, R27, R28, R29, R30, R31, R32, R33: 390; R_0603_1608Metric
U1, U3, U4, U5: HDSP-7503; HDSP-A151
U2: 74HC595; SOIC-16_3.9x9.9mm_P1.27mm

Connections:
+3V3: U2.10 (~SRCLR), U2.16 (VCC); also elsewhere on the board
/leds/spi_clk_in: U2.11 (SRCLK); also elsewhere on the board
/leds/spi_data_in: U2.14 (SER); also elsewhere on the board
/seven_segment_display/digit_1_in: R25.2; also elsewhere on the board
/seven_segment_display/digit_2_in: R34.2; also elsewhere on the board
/seven_segment_display/digit_3_in: R35.2; also elsewhere on the board
/seven_segment_display/digit_4_in: R36.2; also elsewhere on the board
/seven_segment_display/segment_A: R26.1, U1.10 (A), U3.10 (A), U4.10 (A), U5.10 (A)
/seven_segment_display/segment_B: R27.1, U1.9 (B), U3.9 (B), U4.9 (B), U5.9 (B)
/seven_segment_display/segment_C: R29.1, U1.8 (C), U3.8 (C), U4.8 (C), U5.8 (C)
/seven_segment_display/segment_D: R33.1, U1.5 (D), U3.5 (D), U4.5 (D), U5.5 (D)
/seven_segment_display/segment_DP: R31.1, U1.7 (DP), U3.7 (DP), U4.7 (DP), U5.7 (DP)
/seven_segment_display/segment_E: R32.1, U1.4 (E), U3.4 (E), U4.4 (E), U5.4 (E)
/seven_segment_display/segment_F: R28.1, U1.2 (F), U3.2 (F), U4.2 (F), U5.2 (F)
/seven_segment_display/segment_G: R30.1, U1.3 (G), U3.3 (G), U4.3 (G), U5.3 (G)
/seven_segment_display/spi_seven_segment_cs: U2.12 (RCLK); also elsewhere on the board
GND: Q1.2 (E), Q2.2 (E), Q3.2 (E), Q4.2 (E), U2.8 (GND), U2.13 (~OE); also elsewhere on the board
unnamed: Q1.1 (B), R25.1
unnamed: Q1.3 (C), U1.1 (CC), U1.6 (CC)
unnamed: Q2.1 (B), R34.1
unnamed: Q2.3 (C), U3.1 (CC), U3.6 (CC)
unnamed: Q3.1 (B), R35.1
unnamed: Q3.3 (C), U4.1 (CC), U4.6 (CC)
unnamed: Q4.1 (B), R36.1
unnamed: Q4.3 (C), U5.1 (CC), U5.6 (CC)
unnamed: R26.2, U2.15 (QA)
unnamed: R27.2, U2.1 (QB)
unnamed: R28.2, U2.2 (QC)
unnamed: R29.2, U2.3 (QD)
unnamed: R30.2, U2.4 (QE)
unnamed: R31.2, U2.5 (QF)
unnamed: R32.2, U2.6 (QG)
unnamed: R33.2, U2.7 (QH)

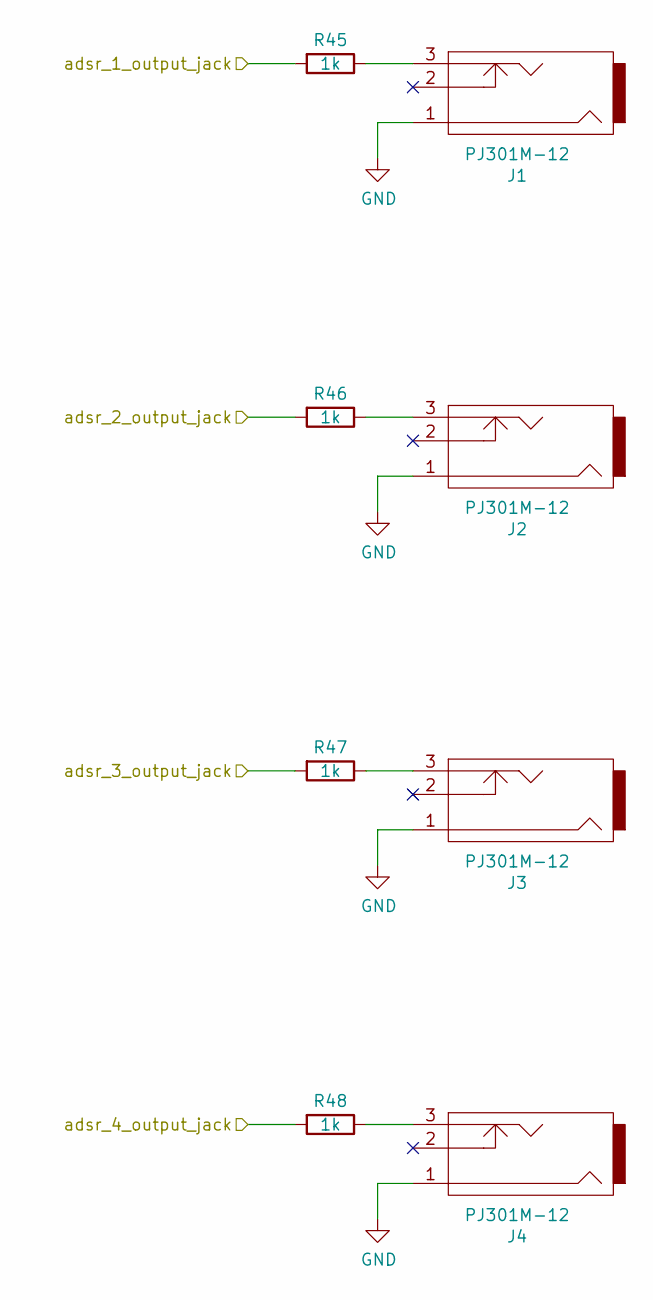
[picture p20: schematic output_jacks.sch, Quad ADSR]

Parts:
J1, J2, J3, J4: PJ301M-12
R45, R46, R47, R48: 1k; R_0603_1608Metric

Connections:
/spi_dacs_and_level_shifters/10vp_adsr_1_out: R45.2; also elsewhere on the board
/spi_dacs_and_level_shifters/10vp_adsr_2_out: R46.2; also elsewhere on the board
/spi_dacs_and_level_shifters/10vp_adsr_3_out: R47.2; also elsewhere on the board
/spi_dacs_and_level_shifters/10vp_adsr_4_out: R48.2; also elsewhere on the board
GND: J1.1, J2.1, J3.1, J4.1; also elsewhere on the board
unnamed: J1.3, R45.1
unnamed: J2.3, R46.1
unnamed: J3.3, R47.1
unnamed: J4.3, R48.1

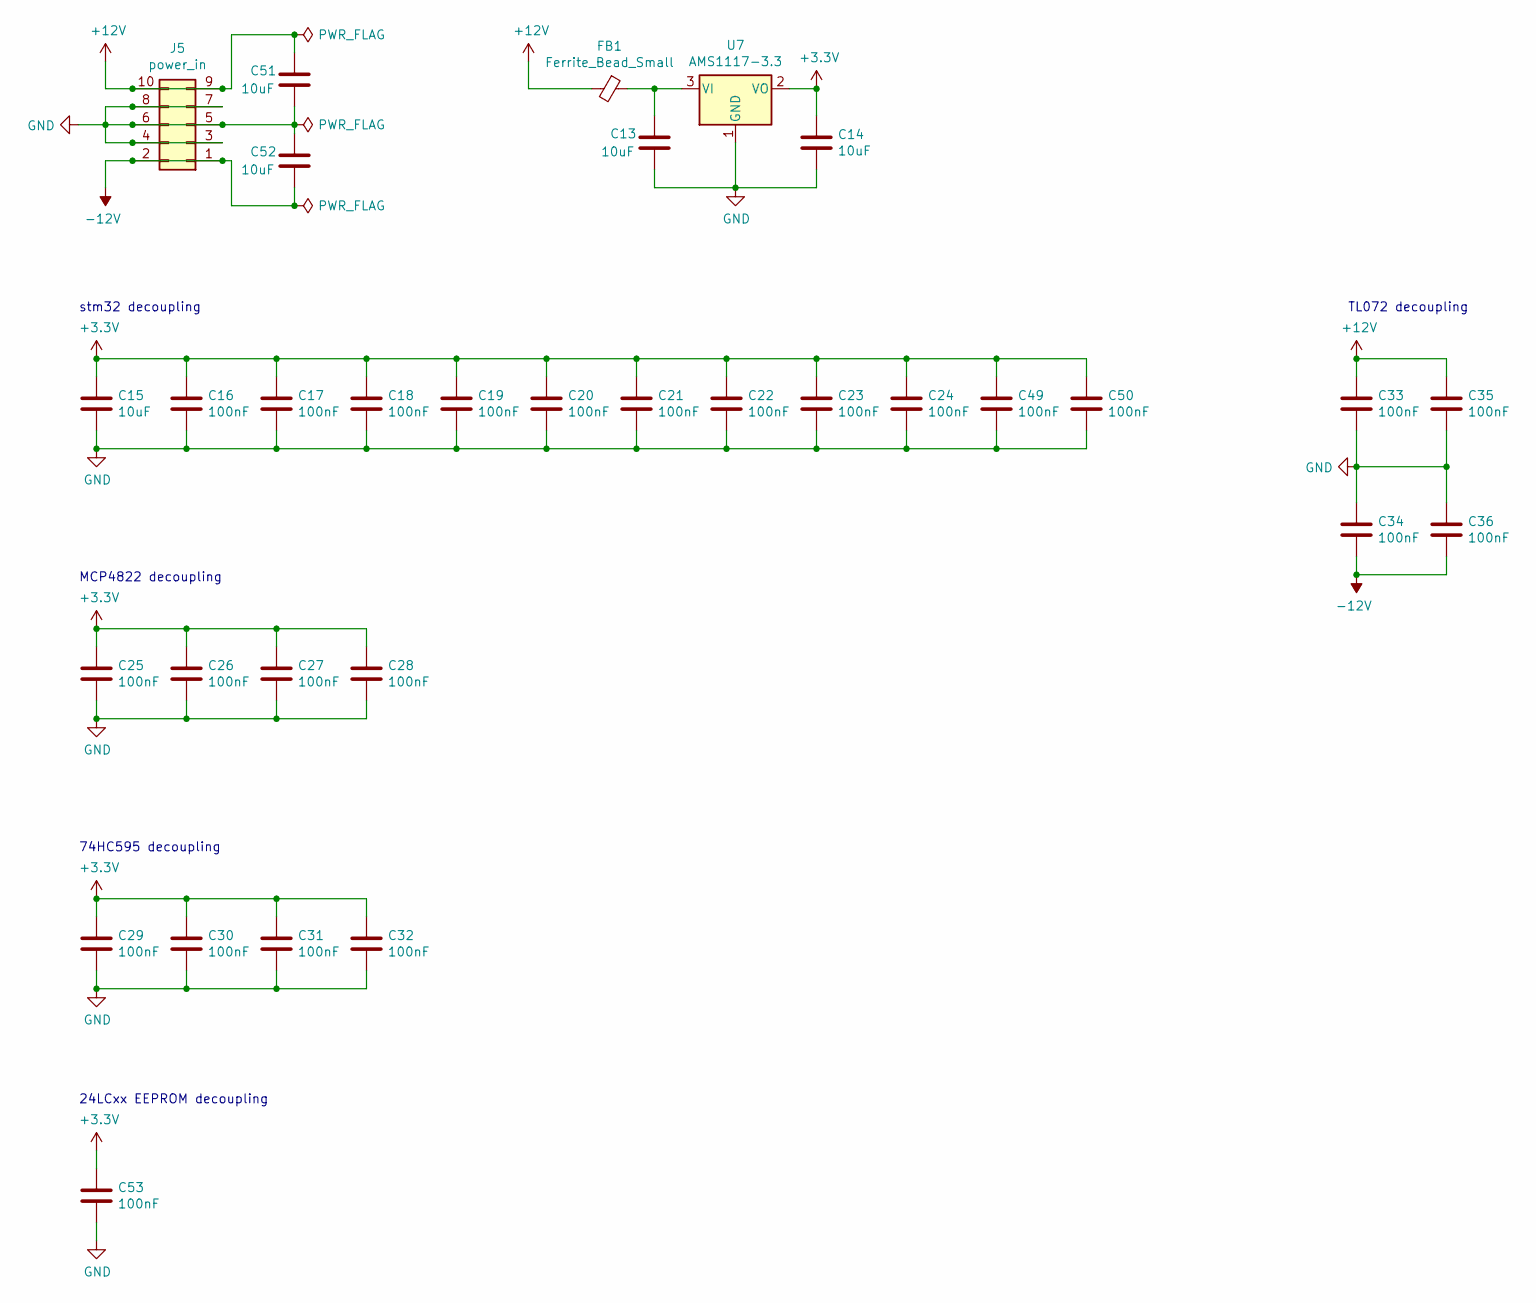
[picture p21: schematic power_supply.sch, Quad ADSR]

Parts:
C13, C51, C52: 10uF; C_1206_3216Metric
C14, C15: 10uF; C_0805_2012Metric
C16, C17, C18, C19, C20, C21, C22, C23, C24, C25, C26, C27, C28, C29, C30, C31, C32, C49, C50, C53: 100nF; C_0402_1005Metric
C33, C34, C35, C36: 100nF; C_0603_1608Metric
FB1: Ferrite_Bead_Small; L_0805_2012Metric
J5: power_in; PinHeader_2x05_P2.54mm_Vertical
U7: AMS1117-3.3; SOT-223-3_TabPin2

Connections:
+3V3: C14.1, C15.1, C16.1, C17.1, C18.1, C19.1, C20.1, C21.1, C22.1, C23.1, C24.1, C25.1, C26.1, C27.1, C28.1, C29.1, C30.1, C31.1, C32.1, C49.1, C50.1, C53.1, U7.2 (VO); also elsewhere on the board
+12V: C33.1, C35.1, C51.1, FB1.2, J5.9, J5.10; also elsewhere on the board
-12V: C34.2, C36.2, C52.2, J5.1, J5.2; also elsewhere on the board
GND: C13.2, C14.2, C15.2, C16.2, C17.2, C18.2, C19.2, C20.2, C21.2, C22.2, C23.2, C24.2, C25.2, C26.2, C27.2, C28.2, C29.2, C30.2, C31.2, C32.2, C33.2, C34.1, C35.2, C36.1, C49.2, C50.2, C51.2, C52.1, C53.2, J5.3, J5.4, J5.5, J5.6, J5.7, J5.8, U7.1 (GND); also elsewhere on the board
unnamed: C13.1, FB1.1, U7.3 (VI)

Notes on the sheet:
stm32 decoupling
MCP4822 decoupling
74HC595 decoupling
TL072 decoupling
24LCxx EEPROM decoupling

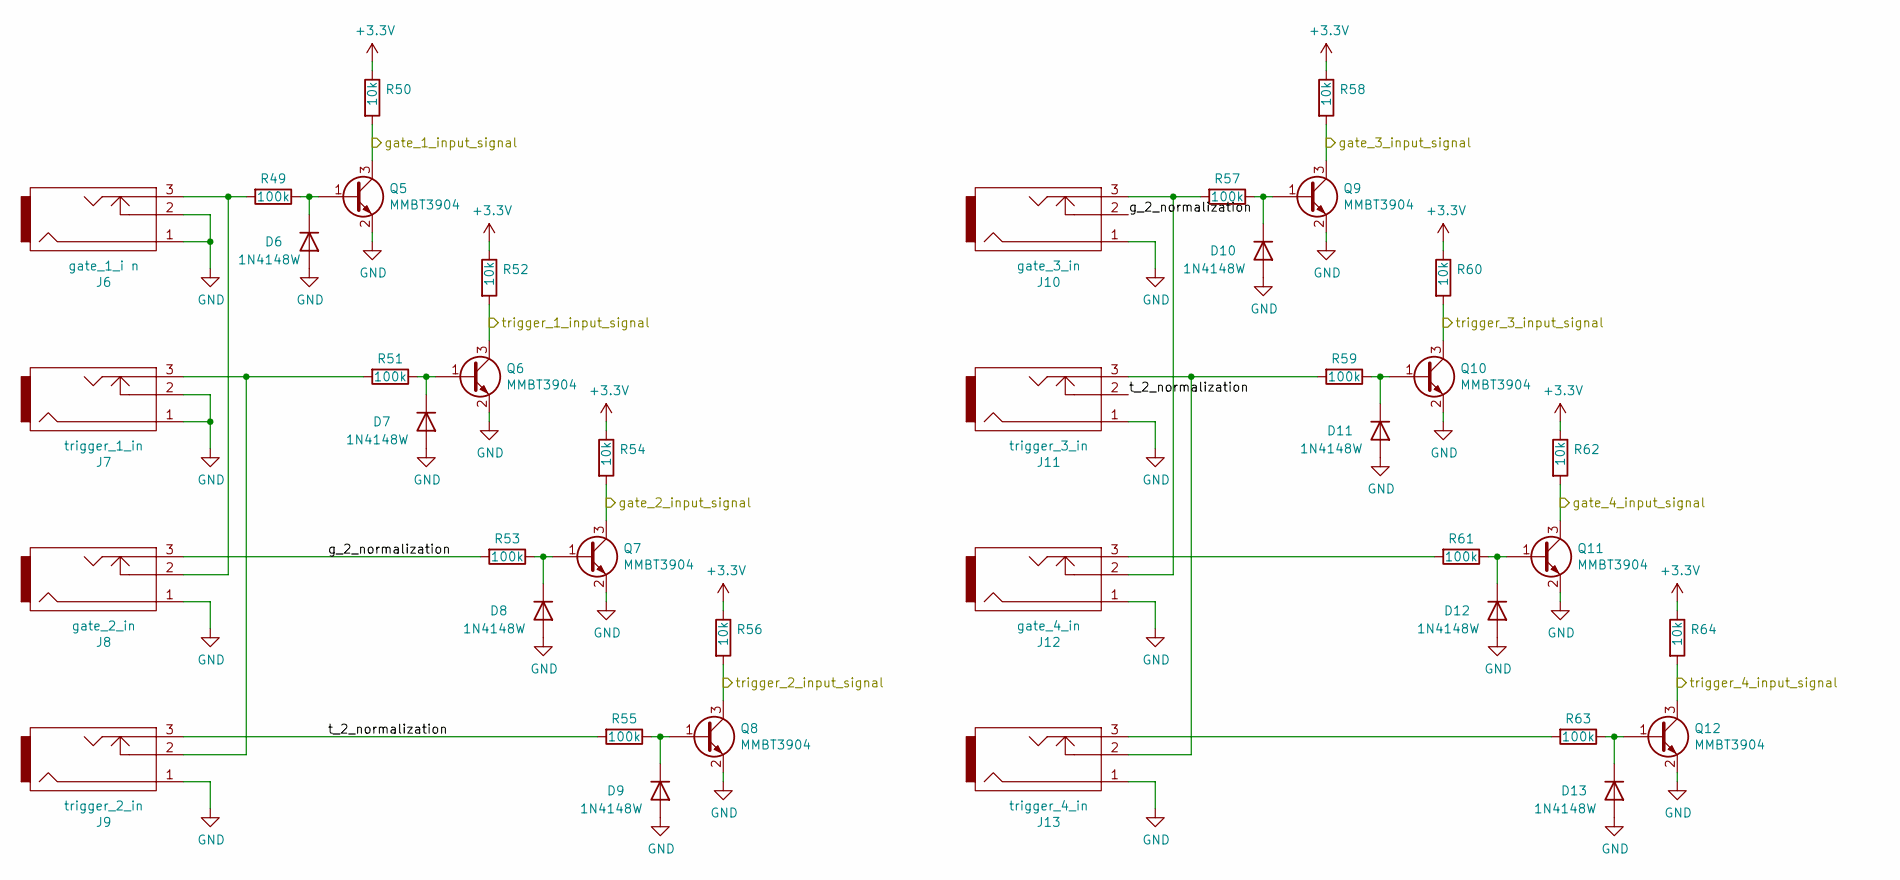
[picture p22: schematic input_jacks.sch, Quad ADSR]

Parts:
D6, D7, D8, D9, D10, D11, D12, D13: 1N4148W; D_SOD-123
J6: gate_1_i n; PJ301M-12
J7: trigger_1_in; PJ301M-12
J8: gate_2_in; PJ301M-12
J9: trigger_2_in; PJ301M-12
J10: gate_3_in; PJ301M-12
J11: trigger_3_in; PJ301M-12
J12: gate_4_in; PJ301M-12
J13: trigger_4_in; PJ301M-12
Q5, Q6, Q7, Q8, Q9, Q10, Q11, Q12: MMBT3904; SOT-23
R49, R51, R53, R55, R57, R59, R61, R63: 100k; R_0603_1608Metric
R50, R52, R54, R56, R58, R60, R62, R64: 10k; R_0603_1608Metric

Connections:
+3V3: R50.1, R52.1, R54.1, R56.1, R58.1, R60.1, R62.1, R64.1; also elsewhere on the board
/input_jacks/g_2_normalization: J8.3, J10.2, R53.2
/input_jacks/t_2_normalization: J9.3, J11.2, R55.2
/stmf32/gate_1_in: Q5.3 (C), R50.2; also elsewhere on the board
/stmf32/gate_2_in: Q7.3 (C), R54.2; also elsewhere on the board
/stmf32/gate_3_in: Q9.3 (C), R58.2; also elsewhere on the board
/stmf32/gate_4_in: Q11.3 (C), R62.2; also elsewhere on the board
/stmf32/trigger_1_in: Q6.3 (C), R52.2; also elsewhere on the board
/stmf32/trigger_2_in: Q8.3 (C), R56.2; also elsewhere on the board
/stmf32/trigger_3_in: Q10.3 (C), R60.2; also elsewhere on the board
/stmf32/trigger_4_in: Q12.3 (C), R64.2; also elsewhere on the board
GND: D6.2 (A), D7.2 (A), D8.2 (A), D9.2 (A), D10.2 (A), D11.2 (A), D12.2 (A), D13.2 (A), J6.1, J6.2, J7.1, J7.2, J8.1, J9.1, J10.1, J11.1, J12.1, J13.1, Q5.2 (E), Q6.2 (E), Q7.2 (E), Q8.2 (E), Q9.2 (E), Q10.2 (E), Q11.2 (E), Q12.2 (E); also elsewhere on the board
unnamed: D6.1 (K), Q5.1 (B), R49.1
unnamed: D7.1 (K), Q6.1 (B), R51.1
unnamed: D8.1 (K), Q7.1 (B), R53.1
unnamed: D9.1 (K), Q8.1 (B), R55.1
unnamed: D10.1 (K), Q9.1 (B), R57.1
unnamed: D11.1 (K), Q10.1 (B), R59.1
unnamed: D12.1 (K), Q11.1 (B), R61.1
unnamed: D13.1 (K), Q12.1 (B), R63.1
unnamed: J6.3, J8.2, R49.2
unnamed: J7.3, J9.2, R51.2
unnamed: J10.3, J12.2, R57.2
unnamed: J11.3, J13.2, R59.2
unnamed: J12.3, R61.2
unnamed: J13.3, R63.2

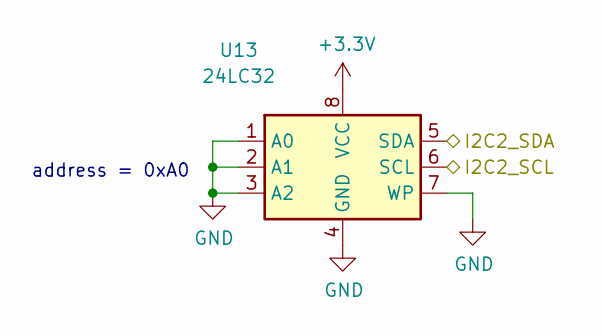
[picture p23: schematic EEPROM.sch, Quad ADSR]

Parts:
U13: 24LC32; SOIC-8_3.9x4.9mm_P1.27mm

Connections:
+3V3: U13.8 (VCC); also elsewhere on the board
/EEPROM/I2C2_SCL: U13.6 (SCL); also elsewhere on the board
/EEPROM/I2C2_SDA: U13.5 (SDA); also elsewhere on the board
GND: U13.1 (A0), U13.2 (A1), U13.3 (A2), U13.4 (GND), U13.7 (WP); also elsewhere on the board

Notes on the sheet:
address = 0xA0

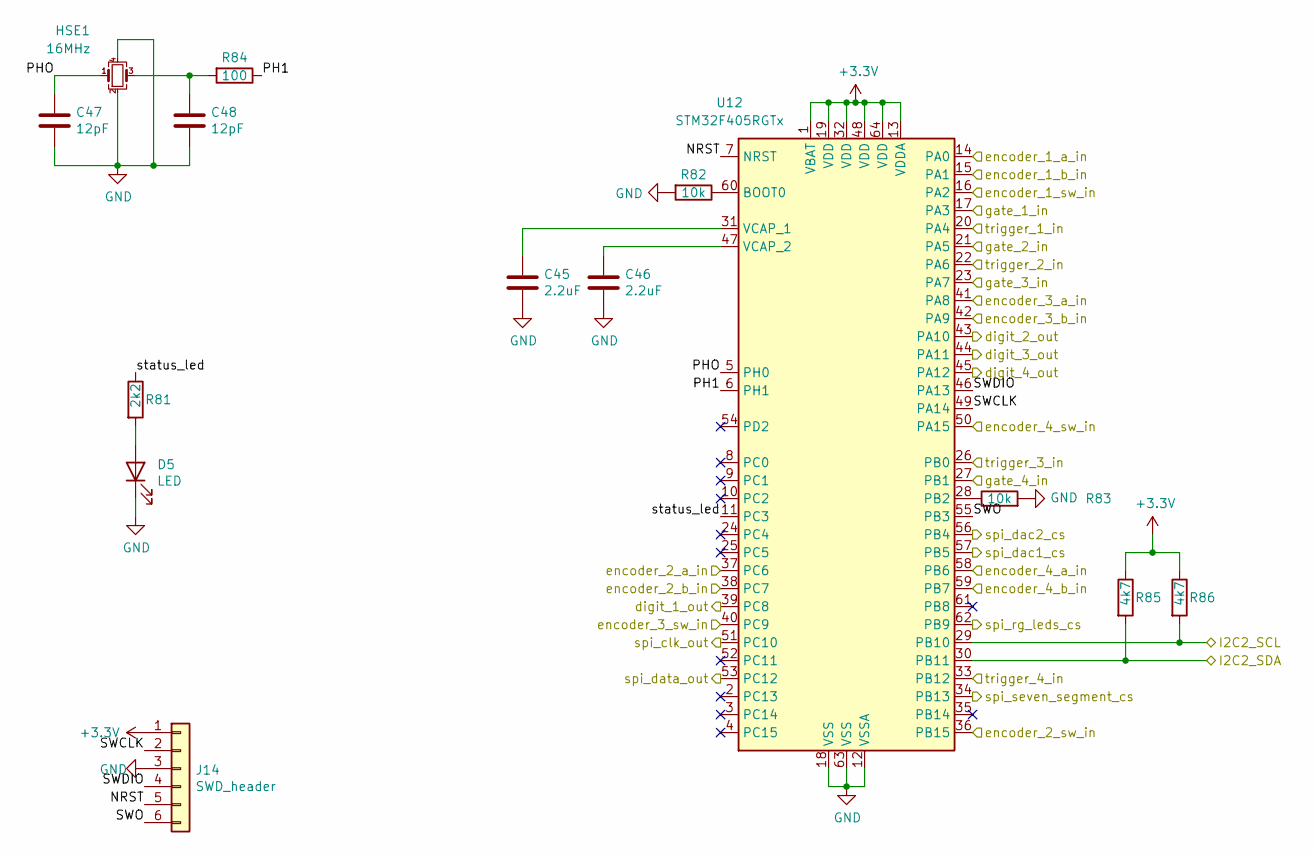
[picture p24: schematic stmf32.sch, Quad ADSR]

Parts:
C45, C46: 2.2uF; C_0603_1608Metric
C47, C48: 12pF; C_0402_1005Metric
D5: LED; LED_0603_1608Metric
HSE1: 16MHz; Crystal_SMD_3225-4Pin_3.2x2.5mm
J14: SWD_header; PinHeader_1x06_P2.54mm_Vertical
R81: 2k2; R_0603_1608Metric
R82, R83: 10k; R_0402_1005Metric
R84: 100; R_0402_1005Metric
R85, R86: 4k7; R_0603_1608Metric
U12: STM32F405RGTx; LQFP-64_10x10mm_P0.5mm

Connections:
+3V3: J14.1, R85.1, R86.1, U12.1 (VBAT), U12.13 (VDDA), U12.19 (VDD), U12.32 (VDD), U12.48 (VDD), U12.64 (VDD); also elsewhere on the board
/EEPROM/I2C2_SCL: R86.2, U12.29 (PB10); also elsewhere on the board
/EEPROM/I2C2_SDA: R85.2, U12.30 (PB11); also elsewhere on the board
/encoders/enc_1_a_out: U12.14 (PA0); also elsewhere on the board
/encoders/enc_1_b_out: U12.15 (PA1); also elsewhere on the board
/encoders/enc_1_sw_out: U12.16 (PA2); also elsewhere on the board
/encoders/enc_2_a_out: U12.37 (PC6); also elsewhere on the board
/encoders/enc_2_b_out: U12.38 (PC7); also elsewhere on the board
/encoders/enc_2_sw_out: U12.36 (PB15); also elsewhere on the board
/encoders/enc_3_a_out: U12.41 (PA8); also elsewhere on the board
/encoders/enc_3_b_out: U12.42 (PA9); also elsewhere on the board
/encoders/enc_3_sw_out: U12.40 (PC9); also elsewhere on the board
/encoders/enc_4_a_out: U12.58 (PB6); also elsewhere on the board
/encoders/enc_4_b_out: U12.59 (PB7); also elsewhere on the board
/encoders/enc_4_sw_out: U12.50 (PA15); also elsewhere on the board
/leds/spi_clk_in: U12.51 (PC10); also elsewhere on the board
/leds/spi_data_in: U12.53 (PC12); also elsewhere on the board
/leds/spi_rg_leds_cs: U12.62 (PB9); also elsewhere on the board
/seven_segment_display/digit_1_in: U12.39 (PC8); also elsewhere on the board
/seven_segment_display/digit_2_in: U12.43 (PA10); also elsewhere on the board
/seven_segment_display/digit_3_in: U12.44 (PA11); also elsewhere on the board
/seven_segment_display/digit_4_in: U12.45 (PA12); also elsewhere on the board
/seven_segment_display/spi_seven_segment_cs: U12.34 (PB13); also elsewhere on the board
/spi_dacs_and_level_shifters/spi_dac1_cs: U12.57 (PB5); also elsewhere on the board
/spi_dacs_and_level_shifters/spi_dac2_cs: U12.56 (PB4); also elsewhere on the board
/stmf32/NRST: J14.5, U12.7 (NRST)
/stmf32/PH1: R84.1, U12.6 (PH1)
/stmf32/PHO: C47.1, HSE1.1, U12.5 (PH0)
/stmf32/SWCLK: J14.2, U12.49 (PA14)
/stmf32/SWDIO: J14.4, U12.46 (PA13)
/stmf32/SWO: J14.6, U12.55 (PB3)
/stmf32/gate_1_in: U12.17 (PA3); also elsewhere on the board
/stmf32/gate_2_in: U12.21 (PA5); also elsewhere on the board
/stmf32/gate_3_in: U12.23 (PA7); also elsewhere on the board
/stmf32/gate_4_in: U12.27 (PB1); also elsewhere on the board
/stmf32/status_led: R81.1, U12.11 (PC3)
/stmf32/trigger_1_in: U12.20 (PA4); also elsewhere on the board
/stmf32/trigger_2_in: U12.22 (PA6); also elsewhere on the board
/stmf32/trigger_3_in: U12.26 (PB0); also elsewhere on the board
/stmf32/trigger_4_in: U12.33 (PB12); also elsewhere on the board
GND: C45.2, C46.2, C47.2, C48.2, D5.1 (K), HSE1.2, HSE1.4, J14.3, R82.2, R83.2, U12.12 (VSSA), U12.18 (VSS), U12.63 (VSS); also elsewhere on the board
unnamed: C45.1, U12.31 (VCAP_1)
unnamed: C46.1, U12.47 (VCAP_2)
unnamed: C48.1, HSE1.3, R84.2
unnamed: D5.2 (A), R81.2
unnamed: R82.1, U12.60 (BOOT0)
unnamed: R83.1, U12.28 (PB2)

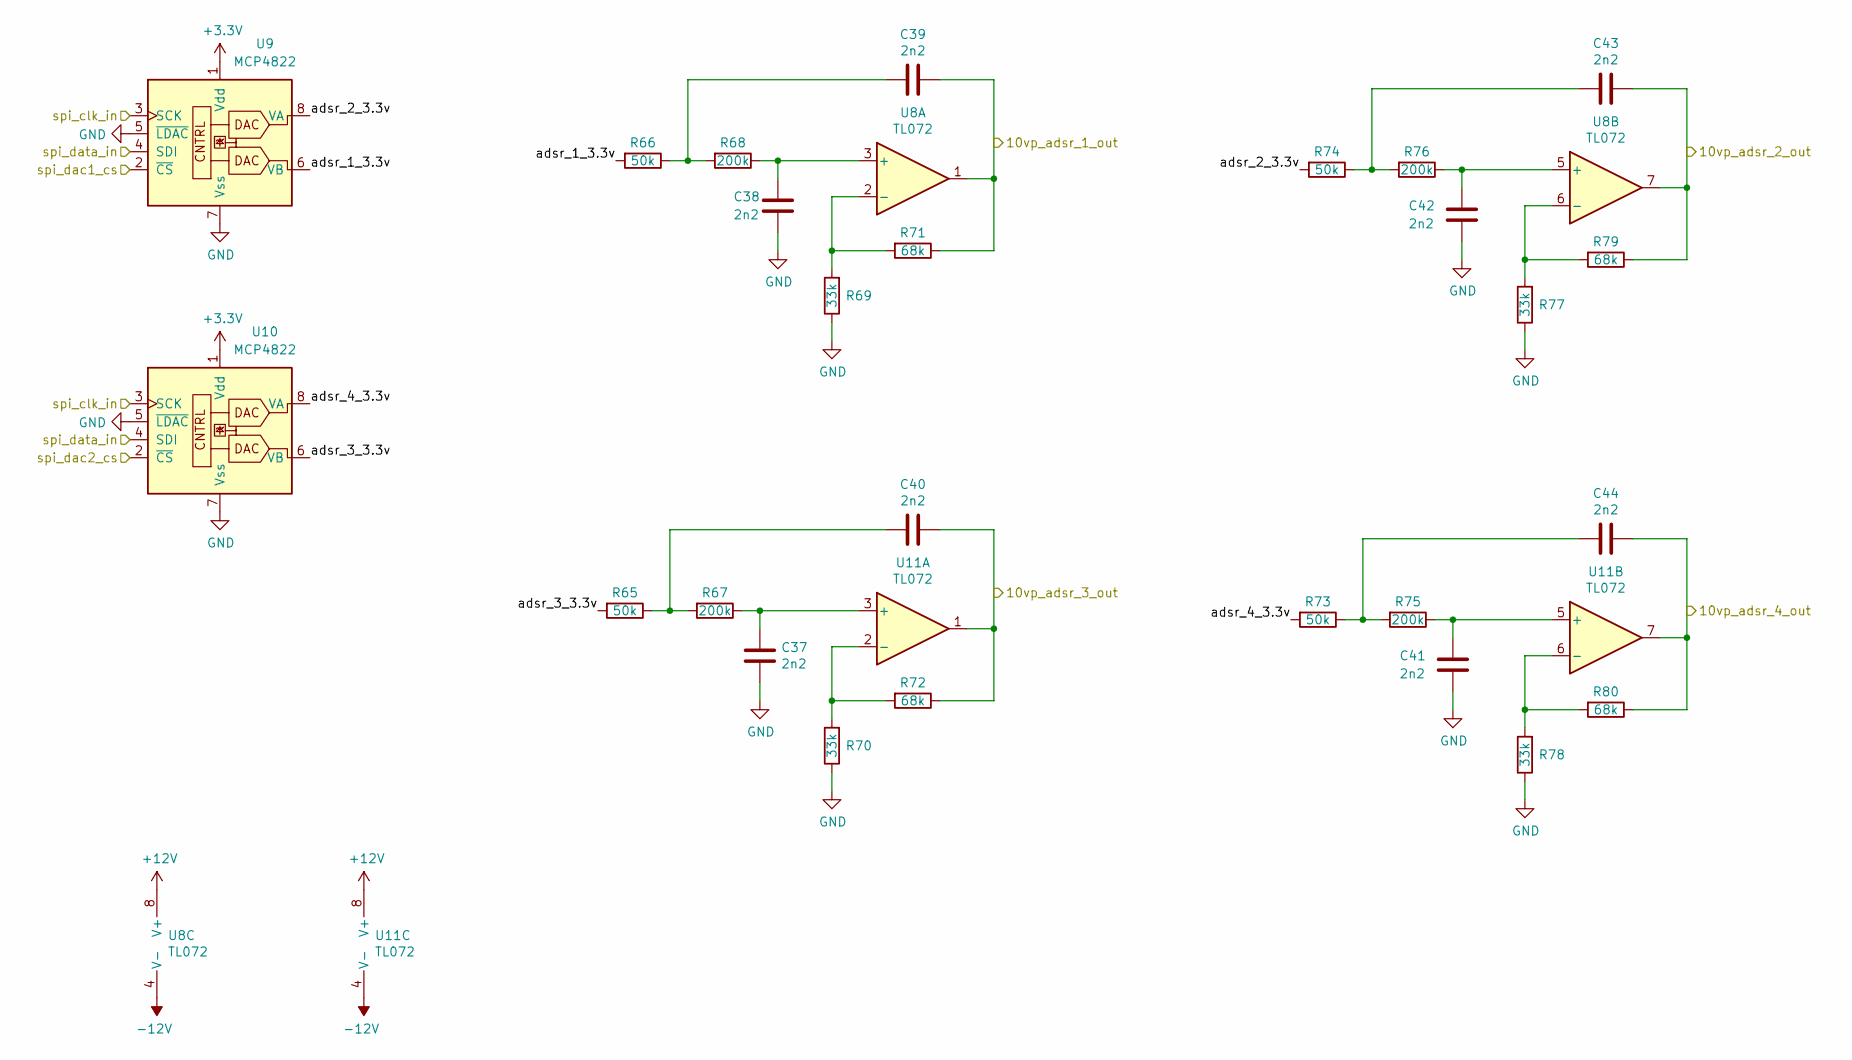
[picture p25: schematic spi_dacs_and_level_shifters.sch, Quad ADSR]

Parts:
C37, C38, C39, C40, C41, C42, C43, C44: 2n2; C_0805_2012Metric_Pad1.15x1.40mm_HandSolder
R65, R66, R73, R74: 50k; R_0603_1608Metric
R67, R68, R75, R76: 200k; R_0603_1608Metric
R69, R70, R77, R78: 33k; R_0603_1608Metric
R71, R72, R79, R80: 68k; R_0603_1608Metric
U8, U11: TL072; SOIC-8_3.9x4.9mm_P1.27mm
U9, U10: MCP4822; SOIC-8_3.9x4.9mm_P1.27mm

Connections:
+3V3: U9.1 (Vdd), U10.1 (Vdd); also elsewhere on the board
+12V: U8.8 (V+), U11.8 (V+); also elsewhere on the board
-12V: U8.4 (V-), U11.4 (V-); also elsewhere on the board
/leds/spi_clk_in: U9.3 (SCK), U10.3 (SCK); also elsewhere on the board
/leds/spi_data_in: U9.4 (SDI), U10.4 (SDI); also elsewhere on the board
/spi_dacs_and_level_shifters/10vp_adsr_1_out: C39.1, R71.1, U8.1; also elsewhere on the board
/spi_dacs_and_level_shifters/10vp_adsr_2_out: C43.1, R79.1, U8.7; also elsewhere on the board
/spi_dacs_and_level_shifters/10vp_adsr_3_out: C40.1, R72.1, U11.1; also elsewhere on the board
/spi_dacs_and_level_shifters/10vp_adsr_4_out: C44.1, R80.1, U11.7; also elsewhere on the board
/spi_dacs_and_level_shifters/adsr_1_3.3v: R66.2, U9.6 (VB)
/spi_dacs_and_level_shifters/adsr_2_3.3v: R74.2, U9.8 (VA)
/spi_dacs_and_level_shifters/adsr_3_3.3v: R65.2, U10.6 (VB)
/spi_dacs_and_level_shifters/adsr_4_3.3v: R73.2, U10.8 (VA)
/spi_dacs_and_level_shifters/spi_dac1_cs: U9.2 (~CS); also elsewhere on the board
/spi_dacs_and_level_shifters/spi_dac2_cs: U10.2 (~CS); also elsewhere on the board
GND: C37.2, C38.2, C41.2, C42.2, R69.1, R70.1, R77.1, R78.1, U9.5 (~LDAC), U9.7 (Vss), U10.5 (~LDAC), U10.7 (Vss); also elsewhere on the board
unnamed: C37.1, R67.1, U11.3 (+)
unnamed: C38.1, R68.1, U8.3 (+)
unnamed: C39.2, R66.1, R68.2
unnamed: C40.2, R65.1, R67.2
unnamed: C41.1, R75.1, U11.5 (+)
unnamed: C42.1, R76.1, U8.5 (+)
unnamed: C43.2, R74.1, R76.2
unnamed: C44.2, R73.1, R75.2
unnamed: R69.2, R71.2, U8.2 (-)
unnamed: R70.2, R72.2, U11.2 (-)
unnamed: R77.2, R79.2, U8.6 (-)
unnamed: R78.2, R80.2, U11.6 (-)

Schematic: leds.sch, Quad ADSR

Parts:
D1, D2, D3, D4: LED_Dual_ACA; LED_D3.0mm-3
R37, R38, R39, R40, R41, R42, R43, R44: 390; R_0603_1608Metric
U6: 74HC595; SOIC-16_3.9x9.9mm_P1.27mm

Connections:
+3V3: U6.10 (~SRCLR), U6.16 (VCC); also elsewhere on the board
/leds/QA: R37.2, U6.15 (QA)
/leds/QB: R38.2, U6.1 (QB)
/leds/QC: R39.2, U6.2 (QC)
/leds/QD: R40.2, U6.3 (QD)
/leds/QE: R41.2, U6.4 (QE)
/leds/QF: R42.2, U6.5 (QF)
/leds/QG: R43.2, U6.6 (QG)
/leds/QH: R44.2, U6.7 (QH)
/leds/spi_clk_in: U6.11 (SRCLK); also elsewhere on the board
/leds/spi_data_in: U6.14 (SER); also elsewhere on the board
/leds/spi_rg_leds_cs: U6.12 (RCLK); also elsewhere on the board
GND: D1.2 (K), D2.2 (K), D3.2 (K), D4.2 (K), U6.8 (GND), U6.13 (~OE); also elsewhere on the board
unnamed: D1.1 (A1), R44.1
unnamed: D1.3 (A2), R43.1
unnamed: D2.1 (A1), R42.1
unnamed: D2.3 (A2), R41.1
unnamed: D3.1 (A1), R40.1
unnamed: D3.3 (A2), R39.1
unnamed: D4.1 (A1), R38.1
unnamed: D4.3 (A2), R37.1

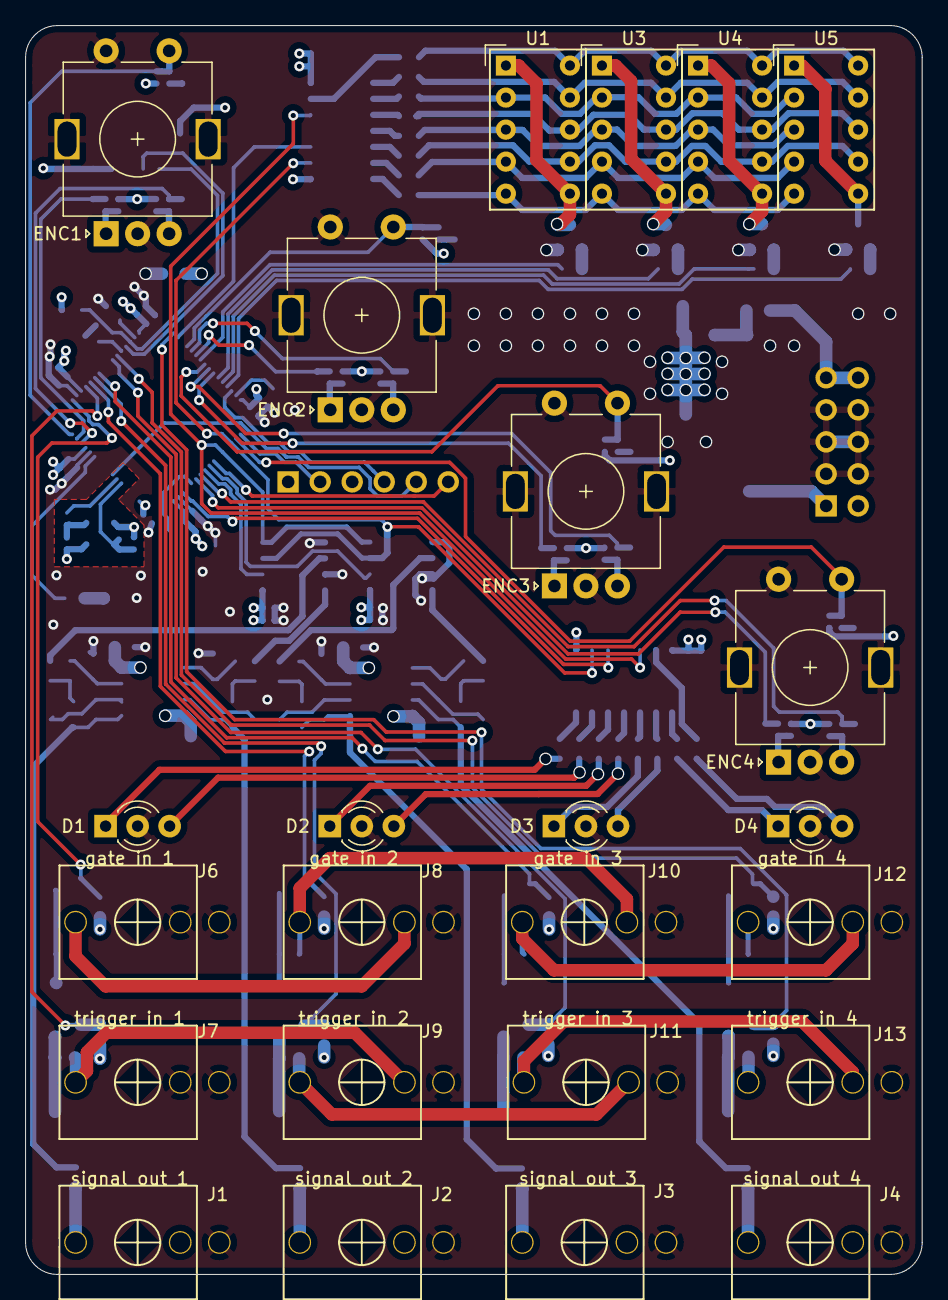
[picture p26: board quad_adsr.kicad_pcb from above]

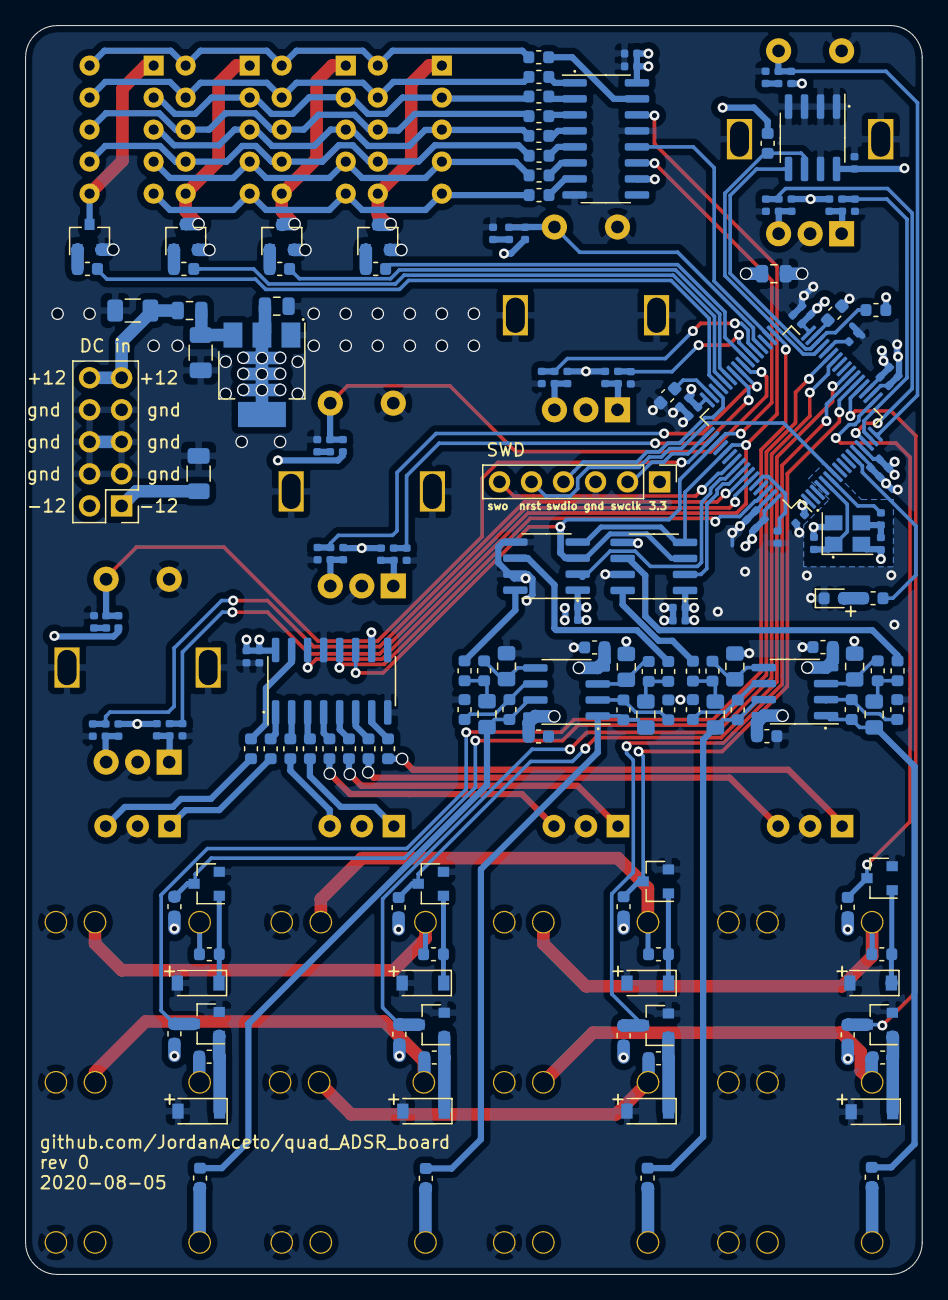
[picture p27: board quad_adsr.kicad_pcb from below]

Board: 4 copper layers, 71.1 x 99.1 mm, 197 parts (173 on the bottom side), 142 nets.

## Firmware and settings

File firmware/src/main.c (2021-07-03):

#include "EEPROM_24LC32.h"
#include "global_data.h"
#include "GPIO.h"
#include "input_processing.h"
#include "interrupts.h"
#include "output_processing.h"
#include "SysTick.h"

int main(void)
{
    // test_EEPROM();

    while (1)
    {
        // TIM6 triggers the fast interrupt for timing critical tasks
        if (interrupt_get_flag(INTERRUPT_FLAG_TIM6))
        {
            poll_gate_and_trigger_inputs();
            tick_ADSRs();
            update_MCP4822_DACs();
        }

        // TIM7 triggers the slower interrupt for updating the UI
        if (interrupt_get_flag(INTERRUPT_FLAG_TIM7))
        {
            poll_encoders();
            poll_pushbuttons();
            update_ADSR_inputs();
            update_seven_segment_display();
            update_bicolor_LEDs();
        }

        // write settings to the EEPROM periodically if the settings have changed
        if (SysTick_Poll_Periodic_Timer(&EEPROM_periodic_timer) && eeprom_save_is_pending())
        {
            store_cached_adsr_settings_in_EEPROM();
        }
    }

    // never reached
    return 0;
}

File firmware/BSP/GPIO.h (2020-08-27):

/*
--|----------------------------------------------------------------------------|
--| FILE DESCRIPTION:
--|   GPIO.h provides the interface for initializing the GPIO pins.
--|   
--| 
--|----------------------------------------------------------------------------|
--| REFERENCES:
--|
--|----------------------------------------------------------------------------|
*/

#ifndef GPIO_H_INCLUDED
#define GPIO_H_INCLUDED

/*
--|----------------------------------------------------------------------------|
--| INCLUDE FILES
--|----------------------------------------------------------------------------|
*/

#include "stm32f4xx.h"

/*
--|----------------------------------------------------------------------------|
--| PUBLIC DEFINES
--|----------------------------------------------------------------------------|
*/

// defines for GPIO pins used by the system follow the pattern below:

/*
--| NAME: xxx_Port
--| DESCRIPTION: the GPIO port for a given GPIO pin
--| TYPE: GPIO_TypeDef *
*/

/*
--| NAME: xxx_Pin
--| DESCRIPTION: the pin number for a given GPIO pin
--| TYPE: uint
*/

/*
--|------------------------------------------|
--| ENCODER PINS
--|------------------------------------------|
*/

/*
--| Encoder 1
*/
#define ENCODER_1_A_GPIO_Port (GPIOA)
#define ENCODER_1_A_Pin (0u)

#define ENCODER_1_B_GPIO_Port (GPIOA)
#define ENCODER_1_B_Pin (1u)

#define ENCODER_1_SWITCH_GPIO_Port (GPIOA)
#define ENCODER_1_SWITCH_Pin (2u)

/*
--| Encoder 2
*/
#define ENCODER_2_A_GPIO_Port (GPIOC)
#define ENCODER_2_A_Pin (6u)

#define ENCODER_2_B_GPIO_Port (GPIOC)
#define ENCODER_2_B_Pin (7u)

#define ENCODER_2_SWITCH_GPIO_Port (GPIOB)
#define ENCODER_2_SWITCH_Pin (15u)

/*
--| Encoder 3
*/
#define ENCODER_3_A_GPIO_Port (GPIOA)
#define ENCODER_3_A_Pin (8u)

#define ENCODER_3_B_GPIO_Port (GPIOA)
#define ENCODER_3_B_Pin (9u)

#define ENCODER_3_SWITCH_GPIO_Port (GPIOC)
#define ENCODER_3_SWITCH_Pin (9u)

/*
--| Encoder 4
*/
#define ENCODER_4_A_GPIO_Port (GPIOB)
#define ENCODER_4_A_Pin (6u)

#define ENCODER_4_B_GPIO_Port (GPIOB)
#define ENCODER_4_B_Pin (7u)

#define ENCODER_4_SWITCH_GPIO_Port (GPIOA)
#define ENCODER_4_SWITCH_Pin (15u)

/*
--|------------------------------------------|
--| GATE PINS
--|------------------------------------------|
*/

/*
--| Gate 1
*/
#define GATE_1_GPIO_Port (GPIOA)
#define GATE_1_Pin (3u)

/*
--| Gate 2
*/
#define GATE_2_GPIO_Port (GPIOA)
#define GATE_2_Pin (5u)

/*
--| Gate 3
*/
#define GATE_3_GPIO_Port (GPIOA)
#define GATE_3_Pin (7u)

/*
--| Gate 4
*/
#define GATE_4_GPIO_Port (GPIOB)
#define GATE_4_Pin (1u)

/*
--|------------------------------------------|
--| TRIGGER PINS
--|------------------------------------------|
*/

/*
--| Trigger 1
*/
#define TRIG_1_GPIO_Port (GPIOA)
#define TRIG_1_Pin (4u)

/*
--| Trigger 2
*/
#define TRIG_2_GPIO_Port (GPIOA)
#define TRIG_2_Pin (6u)

/*
--| Trigger 3
*/
#define TRIG_3_GPIO_Port (GPIOB)
#define TRIG_3_Pin (0u)

/*
--| Trigger 4
*/
#define TRIG_4_GPIO_Port (GPIOB)
#define TRIG_4_Pin (12u)

/*
--|------------------------------------------|
--| SPI3 PINS
--|------------------------------------------|
*/

/*
--| SPI3 SCK
*/
#define SPI3_SCK_GPIO_Port (GPIOC)
#define SPI3_SCK_Pin (10u)

/*
--| SPI3 MISO
*/
#define SPI3_MISO_GPIO_Port (GPIOC)
#define SPI3_MISO_Pin (11u)

/*
--| SPI3 MOSI
*/
#define SPI3_MOSI_GPIO_Port (GPIOC)
#define SPI3_MOSI_Pin (12u)

/*
--| SPI3 DAC 1 CS
*/
#define SPI3_DAC1_CS_GPIO_Port (GPIOB)
#define SPI3_DAC1_CS_Pin (5u)

/*
--| SPI3 DAC 2 CS
*/
#define SPI3_DAC2_CS_GPIO_Port (GPIOB)
#define SPI3_DAC2_CS_Pin (4u)

/*
--| SPI3 SEVEN SEGMENT DISPLAY CS
*/
#define SPI3_SEVEN_SEG_CS_GPIO_Port (GPIOB)
#define SPI3_SEVEN_SEG_CS_Pin (13u)

/*
--| SPI3 RED/GREEN LEDS CS
*/
#define SPI3_RG_LEDS_CS_GPIO_Port (GPIOB)
#define SPI3_RG_LEDS_CS_Pin (9u)

/*
--|------------------------------------------|
--| SEVEN SEGMENT DIGIT SELECT PINS
--|------------------------------------------|
*/

/*
--| SEVEN SEGMENT DIGIT 1 SELECT
*/
#define SEVEN_SEG_DIGIT_1_GPIO_Port (GPIOC)
#define SEVEN_SEG_DIGIT_1_Pin (8u)

/*
--| SEVEN SEGMENT DIGIT 2 SELECT
*/
#define SEVEN_SEG_DIGIT_2_GPIO_Port (GPIOA)
#define SEVEN_SEG_DIGIT_2_Pin (10u)

/*
--| SEVEN SEGMENT DIGIT 3 SELECT
*/
#define SEVEN_SEG_DIGIT_3_GPIO_Port (GPIOA)
#define SEVEN_SEG_DIGIT_3_Pin (11u)

/*
--| SEVEN SEGMENT DIGIT 4 SELECT
*/
#define SEVEN_SEG_DIGIT_4_GPIO_Port (GPIOA)
#define SEVEN_SEG_DIGIT_4_Pin (12u)

/*
--|------------------------------------------|
--| I2C2 PINS
--|------------------------------------------|
*/

/*
--| I2C2 SCL
*/
#define I2C2_SCL_GPIO_Port (GPIOB)
#define I2C2_SCL_Pin (10u)

/*
--| I2C2 SDA
*/
#define I2C2_SDA_GPIO_Port (GPIOB)
#define I2C2_SDA_Pin (11u)

/*
--|------------------------------------------|
--| MISC/DEBUG PINS
--|------------------------------------------|
*/

/*
--| Status LED
*/
#define STATUS_LED_GPIO_Port (GPIOC)
#define STATUS_LED_Pin (3u)
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

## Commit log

2020-05-29 move stm32 docs into their own directory
2020-05-29 remove redundant stm32 docs
2020-05-29 change encoder push-button switch passives
    [encoders.sch, quad_adsr.kicad_pcb, stmf32.sch]
2020-06-25 add EEPROM, big pcb re-design
    [EEPROM.sch, encoders.sch, input_jacks.sch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]
2020-06-29 spread out 1/8" jacks
    [quad_adsr.kicad_pcb]
2020-06-29 add gitignore, remove unnecesary kicad files
    [seven_segment_display.sch]
2020-06-29 remove more redundant kicad files
2020-06-29 replace accidentally deleted kicad file
    [seven_segment_display.sch]
2020-07-14 add front panel, rearrange directories
    [EEPROM.sch, encoders.sch, input_jacks.sch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]
2020-07-31 add title blocks, fix some erc violations
    [EEPROM.sch, encoders.sch, input_jacks.sch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]
2020-07-31 add rendered pcb pics
2020-08-05 increase font size
    [qual_ADSR_front_panel.kicad_pcb]
2020-08-05 add github url and rev info to silk
    [quad_adsr.kicad_pcb]
2020-08-05 change LED current limiting resistors
    [leds.sch, seven_segment_display.sch]
2020-08-05 small pcb treaks
    [quad_adsr.kicad_pcb]
2020-08-18 add title block to front panel
    [qual_ADSR_front_panel.kicad_pcb, qual_ADSR_front_panel.sch]
2020-08-18 reorganize directory structure, add some pics
    [EEPROM.sch, encoders.sch, input_jacks.sch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]
2020-08-19 add pin 1 locations to silk
    [quad_adsr.kicad_pcb]
2020-08-19 regenerate schematic with new LED resistors
2020-08-19 generate interactive BOM
2020-08-19 generate jlcpcb assembly docs
    [quad_adsr_jlc_BOM.csv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]
2020-08-19 generate gerbers
    [quad_adsr-3_3v.gbr, quad_adsr-B_Cu.gbr, quad_adsr-B_Mask.gbr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]
2020-08-26 add front panel gerbers
    [qual_ADSR_front_panel-B_Cu.gbr, qual_ADSR_front_panel-B_Mask.gbr, qual_ADSR_front_panel-B_Paste.gbr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]
2020-08-27 add GPIO pin defines, move SPI pin init code to GPIO.c
2020-08-27 update SPI chip select init
2020-08-27 add I2C GPIO pin init code, parenthesize for consistency
2020-08-27 add bi-color LED software module
2020-08-27 change optimazation back to -O0, -Os broke SPI, pls investigate
2020-08-28 fix bug caused by DAC2 CS pin sharing NJTRST line
    [GPIO.c]
2020-08-28 fix SPI bug where CS went high too soon
    [SPI3.c]
2020-08-28 add interrupts module
2020-08-28 initialize TIM7 and interrupts
2020-08-28 add TIm6 interrupts
2020-08-29 work on bug where pll frequency is wrong
    [TIM6.c, main.c, system_init.c]
2020-08-29 add encoder software module
2020-08-29 move encoder scaling out of input_processing
2020-08-29 initialize encoders
2020-08-29 initialize encoder pins
2020-08-30 make encoders count the correct direction
2020-08-30 fix bicolor LED bug
2021-06-01 rename and tidy up set-encoders fcn
2021-06-02 make set-encoders-to-active-adsr fcn private
2021-06-02 disable interrupts during SPI transmit
2021-06-02 fix bug with lock-to-master transition
    [input_processing.c]
2021-06-03 make fcn public again to fix startup bug
    [input_processing.c, system_init.c]
2021-06-03 use interrupt flags, extract code from ISRs into main
2021-06-10 add I2C2 module
2021-06-10 initialize I2C2
2021-06-17 attempt to fix I2C2 bug, not successful
    [I2C2.c]
2021-06-17 add EEPROM timer object
2021-06-17 make interrupt flag setters private
2021-06-17 reorder pdf schematic pages

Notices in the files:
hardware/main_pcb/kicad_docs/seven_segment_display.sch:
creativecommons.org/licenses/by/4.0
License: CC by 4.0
